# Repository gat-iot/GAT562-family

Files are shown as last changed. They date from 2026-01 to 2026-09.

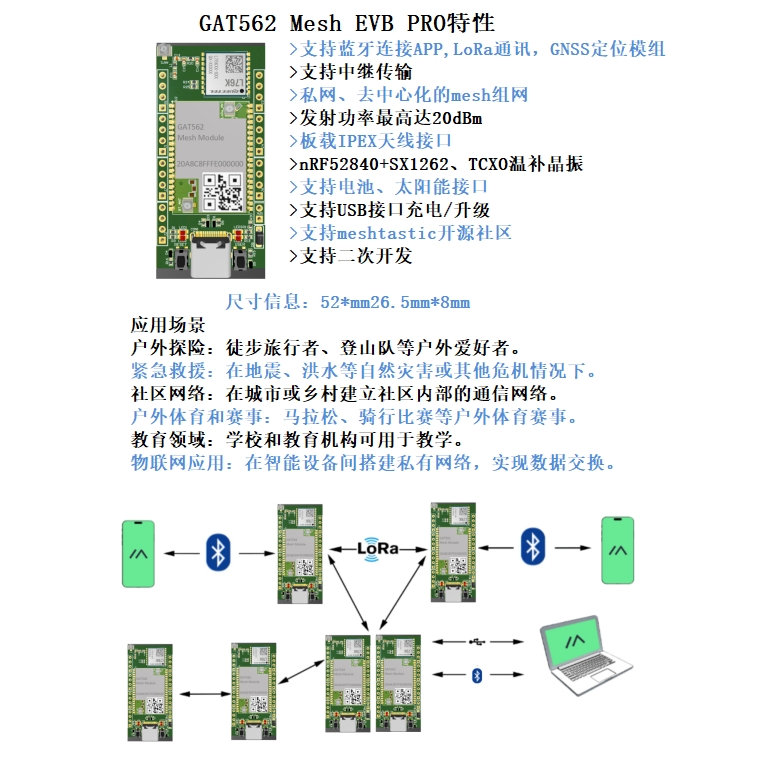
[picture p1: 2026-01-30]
GAT562 Mesh EVB PRO特性图.png

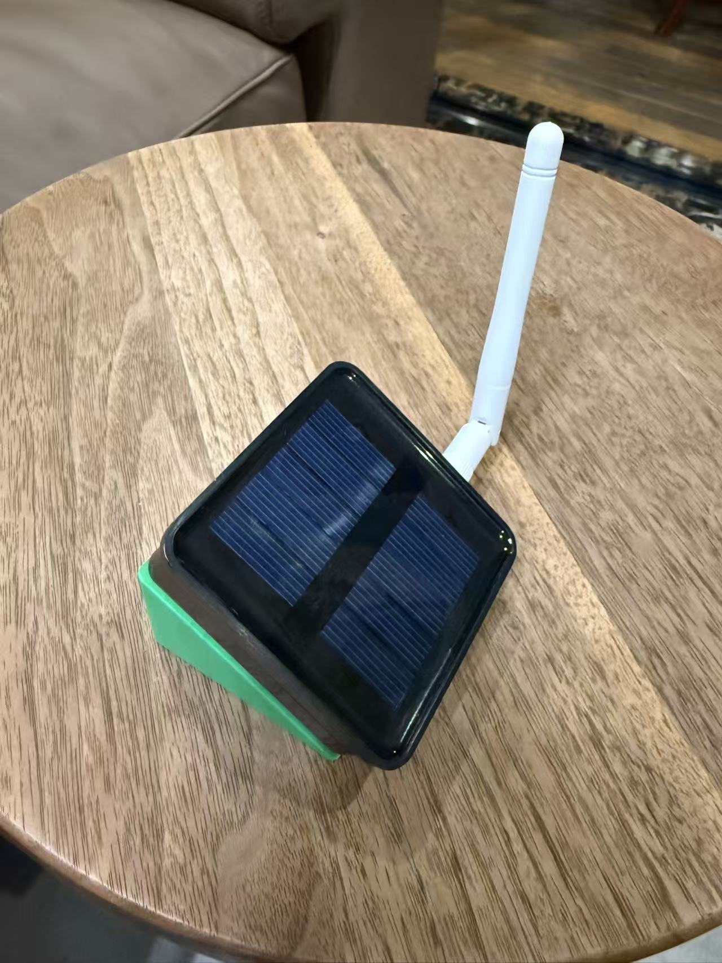
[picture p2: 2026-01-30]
GAT562 Mesh Solar Relay支架安装图.jpg

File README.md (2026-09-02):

GAT562 family介绍

GAT562 family是基于GAT562 Mesh Module 设计的产品系列，GAT562 Module基于nRF52840和SX1262设计的一体化模块，内置nRF52840主芯片，SX1262射频芯片搭配TCXO温补有源晶振，性能稳定，接口丰富，支持LoRa和蓝牙5.0。

GAT562 family目前支持的系统有meshtastic、meshcore、LoRa APRS

meshtastic固件对应仓库链接：https://github.com/gat-iot/firmware

meshcore固件对应官网链接：https://meshcore.co.uk/configurator/

LoRa APRS固件对应仓库链接：https://richonguzman.github.io/nrf52840-web-config/index.html

GAT562 Module接口丰富，拓展性强，模组自带meshtastic固件，支持外接拓展1.3英寸TFT显示屏和GPS模块、LED、蜂鸣器、按键、摇杆等外设功能。

GAT562 Module功耗低，主芯片采用nRF52840的性能与功耗天生优势，无需额外设计，性能稳定，简单可靠。

GAT562 family包含以下产品，种类齐全，形态丰富，可快速完整搭建属于自己的meshtastic网络。

开发板 GAT562 Mesh EVB Pro，适合产品快速验证与使用； GAT562 30S Board,适合产品快速验证与使用；

手持终端 GAT562 Mesh Tracker Pro，适合随身使用； GAT562 30S Mesh Kit， 发射功率30dbm，性能更强，适合贴身使用；

手表终端 GAT562 Mesh watch,适合随身使用；

中继： GAT562 Mesh solar relay（低成本优势）,适合楼顶或者户外中继，与终端终端互联互通，接力更远传输距离； GAT562 Mesh Solar rakay Pro（高性能优势），适合楼顶或者户外中继，与终端终端互联互通，接力更远传输距离； GAT562 Mesh Solar ralay Pro（高性能,高功率优势），适合楼顶或者户外中继，与终端终端互联互通，接力更远传输距离；

GAT562 Mesh family与Meshtastic/meshcore完全兼容，可以在Meshtastic/meshcore网络中更新体验最新的功能。Meshtastic/meshcore是一个社区驱动的开源项目，它允许在没有任何现有或可靠通信基础设施的地区合理的使用LoRa无线电进行远程离网通信。

GAT562 Mesh family与RAK4631模组IO完全兼容，可以烧录RAK4631固件；

优势 去中心化：不依赖中央服务器或基站，每个设备都可作为中继节点转发信息，网络中没有单点故障，即使部分节点出现问题，也不影响整体通信，网络的可靠性和稳定性更高。

长距离通信：利用 LoRa 等无线通信技术，可实现数公里甚至更远距离的通信，在无网络覆盖的偏远地区或广阔的户外空间优势明显。

离线通信：无需依赖互联网或移动网络，在没有手机信号或 Wi-Fi 的地方也能正常通信，满足特殊场景下的通信需求。

低功耗：采用低功耗的蓝牙低功耗（BLE）技术等，对硬件设备的电池消耗较小，可长时间使用，适合携带式设备，减少了充电的频率和难度。

开源可定制：软件开源，开发者能根据自身需求自由修改和扩展代码，进行二次开发，添加新功能或优化现有功能，满足不同用户的个性化需求。

跨平台兼容：支持多种硬件设备和操作系统，用户可选择适合自己的设备接入网络，如手机、平板电脑等，方便不同设备的用户之间进行通信。

成本较低：使用的硬件通常是价格较为低廉的开源硬件模块，相比专业的通信设备，成本大幅降低，易于推广和使用。

用户界面友好：设计了直观、简洁的用户界面，即使是非技术人员也能快速上手，方便用户进行设备配置、信息发送、位置共享等操作。

GAT562 30S Mesh Kit 3D外壳设计文件可自行前往下载：[https://makerworld.com.cn/zh/models/1718656-gat562-30kit-ji-chu-kuan-wai-ke](https://makerworld.com.cn/zh/models/1753346-gat562-22s-30swai-ke#profileId-1932721)

申明 外壳文件为3D打印文件，未经许可禁止商用，如涉及侵权自行承担后果，我方概不负责。

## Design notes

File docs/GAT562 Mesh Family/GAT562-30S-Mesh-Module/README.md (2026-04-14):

# GAT562 30S Mesh Module

## 产品简介

GAT562 30S Mesh Module 是 GAT562 系列的高功率增强版本，LoRa 发射功率提升至 **30 dBm（1 W）**，相比标准版的 22 dBm，通信距离大幅提升，是超远距离通信和太阳能中继的首选。

> **核心硬件**：nRF52840 + SX1262 + TCXO + 外置 PA，**与 RAK4631 模组 IO 完全兼容，可直接烧录 RAK4631 全系列固件**。

## 快速导航

| 文档 | 说明 |
|---|---|
| [概述](./Overview/) | 产品介绍、核心参数、产品系列 |
| [数据手册](./Datasheet/) | 完整技术规格、电气参数、封装信息 |
| [快速入门](./Quickstart/) | 环境搭建、固件烧录、开发指南 |

## 核心参数对比

| 参数 | GAT562 30S | GAT562 标准版 |
|---|---|---|
| LoRa 发射功率 | **30 dBm (1 W)** | 22 dBm (158 mW) |
| 通信距离 | 15 km+ | 8-15 km |
| 峰值电流 | ~900 mA | ~200 mA |
| 供电电压 | 3.3-5 V | 2.0-3.6 V |
| 推荐应用 | 远距离/中继站 | 手持/传感节点 |

## 相关链接

- GitHub: [gat-iot/GAT562-family](https://github.com/gat-iot/GAT562-family)
- Meshtastic: [meshtastic.org](https://meshtastic.org)
- 自定义固件: [gat-iot/meshtastic_fw](https://github.com/gat-iot/meshtastic_fw)

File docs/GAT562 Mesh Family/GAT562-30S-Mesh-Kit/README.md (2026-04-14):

# GAT562 30S Mesh Kit

## 产品简介

GAT562 30S Mesh Kit 是 GAT562 家族的旗舰手持终端套装，基于 GAT562 30S Mesh Module，配备 **30 dBm（1 W）高功率 LoRa**，是户外贴身使用的最强信号选择，适合野外探险、搜救、海上通信等需要超远距离离网通信的场景。

## 核心配置

| 组件 | 型号/规格 |
|---|---|
| **LoRa 模组** | GAT562 30S Mesh Module（**30 dBm 高功率**） |
| **主芯片** | nRF52840 + SX1262 + TCXO |
| **显示屏** | 1.3" TFT |
| **定位** | GPS 模块（内置/外接） |
| **输入** | 按键 + 摇杆 |
| **指示** | LED + 蜂鸣器 |
| **供电** | 内置锂电池（≥ 1000 mAh 推荐） |
| **发射功率** | **30 dBm（1 W）** |
| **通信距离** | 15 km+（开阔地，视天线而定） |

## 与 GAT562 Mesh Tracker Pro 的区别

| 对比项 | GAT562 30S Mesh Kit | GAT562 Mesh Tracker Pro |
|---|---|---|
| 发射功率 | **30 dBm (1 W)** | 22 dBm (158 mW) |
| 通信距离 | **15 km+** | 8-15 km |
| 适用场景 | 超远距离/野外 | 中远距离/城郊 |
| 供电要求 | 高（峰值 900 mA） | 中（峰值 200 mA） |

## 3D 外壳

GAT562 30S Mesh Kit 提供 3D 打印外壳（STL 文件），可在 MakerWorld 下载：

> 📦 [https://makerworld.com.cn/zh/models/1718656-gat562-30kit-ji-chu-kuan-wai-ke](https://makerworld.com.cn/zh/models/1718656-gat562-30kit-ji-chu-kuan-wai-ke)

> ⚠️ 外壳文件为 3D 打印用途，未经许可**禁止商用**，如涉及侵权自行承担后果。

## 固件支持

| 固件 | 来源 | 说明 |
|---|---|---|
| Meshtastic 官方 | 内置 | 英文界面 |
| 中文定制固件 | [pepefrog1234](https://github.com/gat-iot/meshtastic_fw) | 中文界面，支持 30 秒高频位置发送 |

## 相关文档

- [GAT562 30S Mesh Module 数据手册 →](../GAT562-30S-Mesh-Module/Datasheet/)
- [快速入门 →](../GAT562-30S-Mesh-Module/Quickstart/)
- [GitHub 资源](https://github.com/gat-iot/GAT562-family)

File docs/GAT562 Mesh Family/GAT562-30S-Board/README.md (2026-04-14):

# GAT562 30S Board

## 产品简介

GAT562 30S Board 是一款基于 **GAT562 30S Mesh Module** 的开发评估板，搭载 30 dBm 高功率 LoRa 模组，适合需要超远距离通信的产品快速验证与评估。

## 硬件特性

| 特性 | 说明 |
|---|---|
| **核心模组** | GAT562 30S Mesh Module（30 dBm 高功率） |
| **供电** | USB Type-C / DC Jack / 电池接口（≥5V/1A） |
| **天线接口** | IPEX / SMA 可选 |
| **显示接口** | 预留 1.3" TFT 屏幕接口 |
| **调试接口** | USB 烧录 / SWD |
| **尺寸** | 约 85 × 60 mm |

> ⚠️ **供电注意**：30S Board 在高功率发射时峰值电流 ~900 mA，必须使用 5V/1A 以上电源。

## 相关文档

- [GAT562 30S Mesh Module 数据手册 →](../GAT562-30S-Mesh-Module/Datasheet/)
- [快速入门 →](../GAT562-30S-Mesh-Module/Quickstart/)
- [GitHub 资源](https://github.com/gat-iot/GAT562-family)

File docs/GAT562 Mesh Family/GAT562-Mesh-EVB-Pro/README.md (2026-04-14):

# GAT562 Mesh EVB Pro

## 产品简介

GAT562 Mesh EVB Pro 是一款基于 **GAT562 Mesh Module** 的多功能开发评估板，板载 GAT562 模组核心，引出全部 IO 引脚，预装 Meshtastic 固件，适合快速功能验证、产品评估和二次开发。

## 硬件特性

| 特性 | 说明 |
|---|---|
| **核心模组** | GAT562 Mesh Module（nRF52840 + SX1262 + TCXO） |
| **发射功率** | 最高 22 dBm（LoRa PA Boost） |
| **供电方式** | USB Type-C / DC Jack / 电池接口 |
| **调试接口** | 原生 USB（烧录 + 调试）/ SWD 接口 |
| **显示接口** | 预留 1.3" TFT 屏幕接口 |
| **GPS 接口** | 预留 GPS 模块接口（UART） |
| **IO 扩展** | 全部引脚通过排针引出（兼容 RAK5005-O） |
| **板载外设** | LED × 2 / 按键 × 2 / 复位键 |
| **尺寸** | 约 85 × 60 mm |

## IO 引脚图

> 完整 IO 引脚定义图：[GAT562 Mesh EVB PRO IO.png](https://github.com/gat-iot/GAT562-family/blob/main/GAT562%20Mesh%20EVB%20PRO%20IO.png)

## 快速入门

### 步骤 1：连接设备

1. 用 USB-C 数据线连接 EVB Pro 到电脑
2. 蓝色 LED 亮起表示开机正常
3. 在电脑上识别到 USB 串口（COMx）

### 步骤 2：配置 Meshtastic

1. 手机安装 Meshtastic App
2. 打开 App，搜索 BLE 设备
3. 连接后配置频道、节点名称

### 步骤 3：烧录固件

- **Web Flasher**：[meshtastic.org/flasher](https://meshtastic.org/flasher)，选择 RAK4631
- **Arduino IDE**：选择 `WisBlock Core → RAK4631` 开发板

## 扩展接口

| 接口 | 说明 |
|---|---|
| **Slot A / B / C / D** | WisBlock 兼容传感器扩展槽 |
| **IO 排针** | 全部 GPIO 引出 |
| **USB** | 烧录 / 供电 / 串口调试 |
| **SWD** | JTAG / SWD 调试 |
| **GPS 接口** | 串口连接 GPS 模块 |
| **TFT 屏幕** | SPI 接口 1.3" 屏幕 |

## 相关文档

- [GAT562 Mesh Module 数据手册 →](../GAT562-Mesh-Module/Datasheet/)
- [快速入门 →](../GAT562-Mesh-Module/Quickstart/)
- [GitHub 资源](https://github.com/gat-iot/GAT562-family)

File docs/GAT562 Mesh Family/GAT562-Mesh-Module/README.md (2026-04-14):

---
rak_desc
 GAT562 Mesh Module 是一款基于 Nordic nRF52840 + Semtech SX1262 的 LoRa + BLE 融合模组，完全兼容 RAK4631 模组 IO 接口，支持 Meshtastic 开源固件，广泛应用于离网通信、Mesh 网络、定位追踪等物联网场景。
 rak_img
 /assets/images/wisblock/gat562/GAT562-Module.png

 prev
 ../
 next
 ./Overview/

 tags

 gat562
 gat562-30s
 wisblock
 meshtastic
 lora
 bluetooth
 nrf52840
 sx1262
 mesh
 high-power

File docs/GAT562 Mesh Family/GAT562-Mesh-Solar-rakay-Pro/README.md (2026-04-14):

# GAT562 Mesh Solar rakay Pro（高性能太阳能中继）

## 产品简介

GAT562 Mesh Solar rakay Pro 是 GAT562 家族的高性能太阳能中继方案，相比低成本版 Solar Relay，搭载 **22 dBm 高性能模组 + 更大容量的太阳能系统**，适合需要更稳定、更强信号覆盖的长期部署场景。

## 核心配置

| 组件 | 规格 |
|---|---|
| **LoRa 模组** | GAT562 Mesh Module（22 dBm）|
| **中继类型** | 高性能 |
| **太阳能板** | 更大面积（视部署环境）|
| **锂电池** | 更大容量 |
| **天线** | 高增益外置天线 |
| **防护等级** | IP65+ 户外防护外壳（推荐）|

## 与 Solar Relay（低成本版）的区别

| 对比项 | Solar Relay（低成本） | Solar rakay Pro（高性能）|
|---|---|---|
| 太阳能板 | 标准尺寸 | 更大面积 |
| 锂电池 | 基础容量 | 大容量（更长续航）|
| 目标场景 | 短期/临时部署 | 长期稳定运营 |
| 覆盖能力 | 中等 | 强 |

## 相关文档

- [GAT562 Mesh Module 数据手册 →](../GAT562-Mesh-Module/Datasheet/)
- [Meshtastic 官方](https://meshtastic.org)
- [GitHub 资源](https://github.com/gat-iot/GAT562-family)

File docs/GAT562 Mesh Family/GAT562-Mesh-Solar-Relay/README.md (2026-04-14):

# GAT562 Mesh Solar Relay（低成本太阳能中继）

## 产品简介

GAT562 Mesh Solar Relay 是一款基于 GAT562 Mesh Module 的低成本楼顶/户外固定中继设备，预装 Meshtastic 固件，搭配太阳能电池板和锂电池，形成完全自主供电的 Mesh 网络节点，显著延伸 Mesh 通信覆盖范围。

## 核心配置

| 组件 | 规格 |
|---|---|
| **LoRa 模组** | GAT562 Mesh Module（22 dBm） |
| **发射功率** | 22 dBm |
| **中继类型** | 低成本 |
| **供电方案** | 太阳能 + 锂电池 |
| **天线** | 外置高增益天线（推荐 5dBi+） |
| **安装方式** | 壁挂 / 抱杆 |

## 典型部署

```
     楼顶安装
        │
   ┌────▼────┐
   │  LoRa    │◄─────── 接收来自手持终端的消息
   │  天线    │
   └────┬────┘
        │ LoRa Mesh（接力转发）
   ┌────▼────┐
   │ 30S 中继 │◄─────── 继续转发到更远的节点
   └─────────┘
        │
   ┌────▼────┐
   │ 太阳能板 │
   └────┬────┘
        │
   ┌────▼────┐
   │  锂电池  │  24/7 自立供电
   └─────────┘
```

## 配置建议

| 参数 | 推荐值 |
|---|---|
| LoRa 发射功率 | 20~22 dBm（白天）|
| 睡眠间隔 | 按需设置（Mesh 路由自动唤醒）|
| 天线类型 | 全向 5dBi（覆盖均匀）或定向（点对点）|
| 天线安装高度 | 越高越好（视距传播）|
| 锂电池容量 | ≥ 5000 mAh（应对连续阴天）|

## 优势

- ✅ **低成本**：适合大面积铺设
- ✅ **自供电**：太阳能 + 锂电池，零电费
- ✅ **免维护**：Mesh 自组网，自动路由
- ✅ **延伸距离**：显著扩大 Mesh 网络覆盖半径

## 相关文档

- [GAT562 Mesh Module 数据手册 →](../GAT562-Mesh-Module/Datasheet/)
- [Meshtastic 中继配置指南](https://meshtastic.org/docs/)
- [GitHub 资源](https://github.com/gat-iot/GAT562-family)

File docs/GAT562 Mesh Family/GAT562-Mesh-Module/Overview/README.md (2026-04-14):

# GAT562 Mesh Module 概述

## 产品简介

GAT562 Mesh Module 是基于 Nordic nRF52840 + Semtech SX1262 一体化设计的 LoRa + BLE 融合模组，**与 RAK4631 模组 IO 完全兼容，可直接烧录 RAK4631 固件**。模组搭配 TCXO 温补有源晶振，性能稳定，接口丰富，预装 Meshtastic 开源固件，开箱即用。

## 核心特性

| 特性 | 说明 |
|---|---|
| **主芯片** | Nordic nRF52840 (ARM Cortex-M4, 64MHz, 1MB Flash, 256KB RAM) |
| **射频芯片** | Semtech SX1262 LoRa |
| **通信方式** | LoRa + BLE 5.0 |
| **温补晶振** | TCXO（提升频率稳定性与通信距离） |
| **发射功率** | 标准模组：最高 22 dBm（LoRa PA Boost） |
| **接收灵敏度** | -148 dBm（LoRa @ SF12, BW 125kHz） |
| **睡眠功耗** | 低至 2 µA（深度睡眠模式） |
| **供电电压** | 2.0 ~ 3.6 V |
| **工作温度** | -40°C ~ +85°C |
| **模块尺寸** | 约 20 × 30 mm |
| **接口** | UART / I2C / GPIO / USB / SWD |
| **固件** | 预装 Meshtastic，支持外接 1.3" TFT 显示屏、GPS、LED、蜂鸣器、按键、摇杆 |
| **兼容性** | 与 RAK4631 模组 IO 100% 兼容，可烧录 RAK4631-Arduino / RUI3 固件 |

## 支持频段

| 型号后缀 | 适用地区 | 频率范围 |
|---|---|---|
| GAT562(L) | 中国 | CN470 |
| GAT562(L) | 欧洲 | EU433 |
| GAT562(H) | 欧洲 | EU868 |
| GAT562(H) | 北美 | US915 |
| GAT562(H) | 澳大利亚 | AU915 |
| GAT562(H) | 韩国 | KR920 |
| GAT562(H) | 亚洲 | AS923-1/2/3/4 |
| GAT562(H) | 印度 | IN865 |
| GAT562(H) | 俄罗斯 | RU864 |

> **提示**：购买时请确认型号（H = 高频段 / L = 低频段）符合您所在地区的无线电法规。

## 产品系列

GAT562 模组系列包括：

| 产品 | 描述 | 适用场景 |
|---|---|---|
| **GAT562 Mesh Module** | 基础模组，22 dBm 发射功率 | 产品二次开发设计 |
| **GAT562 30S Mesh Module** | 增强模组，30 dBm 发射功率 | 远距离产品二次开发 |
| **GAT562 Mesh EVB Pro** | 开发板 | 快速验证与评估 |
| **GAT562 30S Board** | 30S 开发板 | 快速验证 30S 模组 |
| **GAT562 Mesh Tracker Pro** | 手持终端 | 便携使用 |
| **GAT562 30S Mesh Kit** | 30S 手持终端套装 | 强信号贴身设备 |
| **GAT562 Mesh Watch** | 手表形态终端 | 可穿戴场景 |
| **GAT562 Mesh Solar Relay** | 低成本太阳能中继 | 楼顶/户外固定中继 |
| **GAT562 Mesh Solar rakay Pro** | 高性能太阳能中继 | 强性能固定中继 |
| **GAT562 30S Mesh Solar rakay Pro** | 高功率太阳能中继 | 远距离固定中继 |

## 系统架构

```
┌─────────────────────────────────────┐
│         GAT562 Mesh Module          │
│  ┌───────────────┐  ┌────────────┐ │
│  │  nRF52840     │  │  SX1262    │ │
│  │  (MCU)        │◄─┤  (LoRa RF) │ │
│  │               │  │            │ │
│  │  64MHz ARM    │  │  TCXO      │ │
│  │  1MB Flash    │  │  22dBm     │ │
│  └───────┬───────┘  └──────┬─────┘ │
│          │                 │       │
│          │    BLE 5.0      │       │
│          │    LoRa         │       │
│          └───────┬─────────┘       │
│                  │                 │
│            I/O Port                │
│     (UART / I2C / GPIO / USB)      │
└─────────────────────────────────────┘
```

## 扩展外设支持

GAT562 Mesh Module 模组支持丰富的外部设备扩展：

- **显示屏**：1.3 英寸 TFT 屏幕（SPI 接口）
- **定位模块**：GPS 模块（串口连接）
- **输入设备**：按键、摇杆
- **指示输出**：LED 指示灯、蜂鸣器
- **无线连接**：蓝牙 5.0（近场配置与数据传输）
- **LoRa Mesh**：点对点、Mesh 网络自组网

## Mesh 网络优势

- **去中心化**：无单点故障，每个节点均可转发
- **长距离**：LoRa 穿透性强，支持数公里通信
- **离线通信**：无需互联网，手机无信号也能工作
- **低功耗**：nRF52 架构天然低功耗，待机持久
- **开源可定制**：Meshtastic 固件完全开源，支持二次开发
- **跨平台**：Android / iOS / Web 多端管理

## 与 RAK4631 的关系

GAT562 Mesh Module 基于与 RAK4631 相同的核心硬件平台（nRF52840 + SX1262），两者的主要区别：

| 对比项 | RAK4631 | GAT562 Mesh Module |
|---|---|---|
| **核心硬件** | nRF52840 + SX1262 | nRF52840 + SX1262 |
| **IO 接口** | WisBlock 连接器 | WisBlock 连接器（兼容） |
| **官方固件** | RAK4631-Arduino / RUI3 | Meshtastic（预装） |
| **显示屏** | 需外接 | 内置 1.3" TFT 支持 |
| **GPS** | 需外接 | 支持内置/外接 |
| **封装** | WisBlock Core 模块 | 模组形态 |
| **RAK4631 固件** | 原生支持 | **完全兼容，可直接烧录** |

## 资源链接

- **Meshtastic 官方**：[https://meshtastic.org](https://meshtastic.org)
- **Meshtastic 固件**：[https://github.com/gat-iot/meshtastic_fw](https://github.com/gat-iot/meshtastic_fw)
- **GAT562 GitHub**：[https://github.com/gat-iot/GAT562-family](https://github.com/gat-iot/GAT562-family)
- **RAK4631 文档**：[RAK4631 WisBlock Core](/RAKWireless/rakwireless-docs/blob/master/docs/Product-Categories/WisBlock/RAK4631/README.md)

## 下一步

- [快速入门 →](./Quickstart/)  — 环境搭建与固件烧录
- [数据手册 →](./Datasheet/)  — 完整技术规格

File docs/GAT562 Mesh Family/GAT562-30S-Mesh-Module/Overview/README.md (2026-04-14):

# GAT562 30S Mesh Module 概述

## 产品简介

GAT562 30S Mesh Module 是 GAT562 家族中的**高性能增强版本**，相较于标准 GAT562 Mesh Module，其核心升级在于内置外置功率放大器（PA），LoRa 发射功率从标准版的 22 dBm 提升至 **30 dBm（1 W）**，大幅扩展通信覆盖范围，尤其适合山区、海上、荒野等超远距离通信场景。

其他核心配置与 GAT562 Mesh Module 保持一致，同样基于 nRF52840 + SX1262 + TCXO，**与 RAK4631 模组 IO 完全兼容，可直接烧录 RAK4631 全系列固件**。

## 核心特性

| 特性 | GAT562 30S | GAT562 标准版 | 说明 |
|---|---|---|---|
| **LoRa 发射功率** | **30 dBm (1 W)** | 22 dBm (158 mW) | 外置 PA，显著提升通信距离 |
| **主芯片** | nRF52840 | nRF52840 | ARM Cortex-M4, 64MHz |
| **射频芯片** | SX1262 + TCXO | SX1262 + TCXO | 性能一致 |
| **BLE 发射功率** | +4 dBm | +4 dBm | — |
| **通信距离** | 15 km+（开阔地） | 8-15 km（开阔地） | 视天线和环境而定 |
| **睡眠功耗** | ~2 µA | ~2 µA | 仅 MCU 休眠 |
| **供电电压** | 3.3 ~ 5 V（增强PA供电） | 2.0 ~ 3.6 V | 30S 需更高供电电流 |
| **RAK4631 兼容** | ✅ 完全兼容 | ✅ 完全兼容 | 固件可直接互换 |

## 典型功耗对比

| 模式 | GAT562 30S | GAT562 标准版 |
|---|---|---|
| 深度睡眠 | ~2 µA | ~2 µA |
| 接收 (LoRa) | ~18 mA | ~17 mA |
| 发射 @17 dBm | ~180 mA | ~92 mA |
| **发射 @30 dBm** | **~900 mA** | N/A |
| **发射 @22 dBm** | **~200 mA** | ~125 mA |

> ⚠️ **注意**：30 dBm 高功率发射时峰值电流可达 ~900 mA，请确保供电能力充足（推荐 5V/1A 以上），并注意散热。

## 适用场景

| 场景 | 推荐版本 | 说明 |
|---|---|---|
| 城市近距离 Mesh | GAT562 标准版 | 低功耗够用 |
| 郊区 / 城郊通信 | 两者皆可 | 标准版 22 dBm 可覆盖 |
| **山区 / 海上通信** | **GAT562 30S** | 30 dBm 穿透力强 |
| **野外探险 / 搜救** | **GAT562 30S** | 超远距离通信 |
| 太阳能中继站 | GAT562 30S | 高功率中继首选 |
| 低功耗传感节点 | GAT562 标准版 | 电池供电友好 |

## 支持频段（与 GAT562 一致）

| 型号后缀 | 地区 | 频率 |
|---|---|---|
| 30S(L) | 中国 / 欧洲低频 | CN470 / EU433 |
| 30S(H) | 全球高频地区 | EU868 / US915 / AU915 / KR920 / AS923 / IN865 / RU864 |

## 产品定位

```
GAT562 产品系列定位

  远距离 ←————————————————————————————→ 近距离
     │                                              │
     │  ┌──────────────────────────────┐             │
     │  │  GAT562 30S Series            │             │
     │  │  30 dBm · 太阳能中继首选       │             │
     │  └──────────────────────────────┘             │
     │  ┌──────────────────────────────┐             │
     │  │  GAT562 Standard Series      │             │
  ┌──┴──┴──────────────────────────────┴────────┐   │
  │  22 dBm · 手持终端 / 开发板 / 模组             │   │
  └──────────────────────────────────────────────┘   │
```

## 3D 外壳设计

GAT562 30S Mesh Kit 的 3D 外壳设计文件（STL）可在 MakerWorld 下载：

> [https://makerworld.com.cn/zh/models/1718656-gat562-30kit-ji-chu-kuan-wai-ke](https://makerworld.com.cn/zh/models/1718656-gat562-30kit-ji-chu-kuan-wai-ke)

外壳为 3D 打印设计文件，未经许可**禁止商用**，如涉及侵权由使用者自行承担。

## 资源链接

- **硬件设计文件**：[gat-iot/GAT562-family](https://github.com/gat-iot/GAT562-family)
- **Meshtastic 固件**：[meshtastic.org](https://meshtastic.org)
- **自定义固件**（开源中文版）：[gat-iot/meshtastic_fw](https://github.com/gat-iot/meshtastic_fw)

## 下一步

- [快速入门 →](./Quickstart/)
- [数据手册 →](./Datasheet/)

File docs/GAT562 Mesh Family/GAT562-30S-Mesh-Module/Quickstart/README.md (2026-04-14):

# GAT562 30S Mesh Module 快速入门

## 与 GAT562 标准版的差异

GAT562 30S 的快速入门流程与 GAT562 标准版基本一致，主要差异在于：

| 差异项 | 说明 |
|---|---|
| **供电要求更高** | 30 dBm 发射时峰值电流 ~900 mA，必须使用 ≥5V/1A 电源 |
| **天线接口** | 30S 采用 IPEX/u.FL 射频座（非邮票孔），需使用 IPEX 天线线或转接线 |
| **发热注意** | 长时间 30 dBm 发射时模组会发热，建议加强散热 |

## 供电注意事项

> ⚠️ **关键警告**：GAT562 30S 在 30 dBm 发射时峰值电流约 **900 mA**。如果使用 USB 供电，请确保使用 **USB 3.0 端口**或 **5V/1A 以上**的电源适配器。如果使用锂电池供电，请使用 **3.7V 锂聚合物电池（容量 ≥ 1000 mAh）**。

**推荐供电方案：**
```
✅ 推荐：
  - USB 5V/1A 以上电源适配器 + USB-C 数据线
  - 3.7V LiPo 电池（≥1000mAh）+ USB 充电管理模块
  - 太阳能电池板 + LiPo 电池（太阳能中继场景）

❌ 不推荐：
  - USB 2.0 电脑端口（仅提供 500mA）
  - 直接使用 3.3V/500mA 电源（供电不足，发射会断电重启）
```

## 天线选择

| 天线类型 | 适用场景 | 建议 |
|---|---|---|
| IPEX 1/4 波段天线 | 便携设备 | 小型化，轻便 |
| SMA 直立天线（3dBi） | 固定中继 | 增益更高 |
| SMA 胶棒天线（5dBi） | 远距离固定点 | 高增益首选 |
| 外置高增益天线 | 楼顶中继站 | 10dBi+ 全向/定向天线 |

> **天线匹配**：确保天线阻抗为 **50 Ω**，并使用阻抗匹配的射频线缆（如同轴线）。

## Meshtastic 固件烧录

### 方法一：Web Flasher（推荐）

1. 访问 [meshtastic.org/flasher](https://meshtastic.org/flasher)
2. 选择目标设备：`RAK4631`（GAT562 30S IO 兼容）
3. 选择版本和频段（与您的 30S 模组匹配）
4. 用 USB 连接设备
5. 点击 **Flash**

### 方法二：蓝牙 OTA

1. 开机后，打开 Meshtastic App
2. 连接设备（BLE）
3. 设置 → 检查固件更新 → 安装

### 方法三：自定义开源固件

pepefrog1234 提供了 GAT562 30S 专用 Meshtastic 固件（开源中文界面，位置发送间隔可缩短至 30 秒）：

> **仓库**：[https://github.com/gat-iot/meshtastic_fw](https://github.com/gat-iot/meshtastic_fw)

特点：
- ✅ 支持中文界面
- ✅ 位置发送间隔最短 **30 秒**（适合高频追踪场景）
- ⚠️ 电池电量显示可能不准确
- ⚠️ 建议充分测试后再用于生产环境

## 固件更新邮件

如需获取最新固件，请发邮件至：

> 📧 **farce.chen@foxmail.com**

## LoRa 参数配置建议（30S 专用）

由于 30 dBm 高功率特性，建议以下配置：

| 场景 | 发射功率 | 扩频因子 | 带宽 | 说明 |
|---|---|---|---|---|
| 超远距离固定中继 | 30 dBm | SF10 | 125 kHz | 最大覆盖 |
| 户外探险（平衡模式） | 22 dBm | SF9 | 250 kHz | 距离与功耗平衡 |
| 低功耗传感器节点 | 10 dBm | SF7 | 500 kHz | 省电优先 |

## 太阳能中继应用

GAT562 30S 是太阳能中继站的理想选择：

```
┌──────────────────────────────────────────────┐
│                                              │
│  ┌─────────┐    LoRa Mesh     ┌─────────┐  │
│  │ 手持终端 │◄──────────────►│ 30S 中继 │  │
│  └─────────┘    (30 dBm)      └────┬────┘  │
│                                     │        │
│                              ┌──────▼────┐  │
│                              │  太阳能板  │  │
│                              └──────┬────┘  │
│                                     │        │
│                              ┌──────▼────┐  │
│                              │ LiPo 电池 │  │
│                              │  (供电)   │  │
│                              └───────────┘  │
└──────────────────────────────────────────────┘
```

---

## 相关文档

- [GAT562 30S Mesh Module 概述 →](./)
- [数据手册 →](../Datasheet/)
- [Meshtastic 官方文档](https://meshtastic.org/docs/)
- [MakerWorld 3D 外壳](https://makerworld.com.cn/zh/models/1718656-gat562-30kit-ji-chu-kuan-wai-ke)

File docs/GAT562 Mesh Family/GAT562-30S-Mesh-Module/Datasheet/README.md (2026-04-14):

# GAT562 30S Mesh Module 数据手册

## 硬件规格（与 GAT562 标准版对比）

### 核心差异：功率放大器（PA）

| 参数 | GAT562 30S | GAT562 标准版 |
|---|---|---|
| **LoRa 发射功率** | **30 dBm (1 W)** | 22 dBm |
| PA 架构 | 外置 PA + SX1262 | SX1262 内置 PA（PA_BOOST） |
| 典型 Tx 电流 @30 dBm | ~900 mA | N/A |
| 典型 Tx 电流 @22 dBm | ~200 mA | ~125 mA |
| 典型 Tx 电流 @17 dBm | ~180 mA | ~92 mA |
| 供电电压范围 | 3.3 V ~ 5 V | 2.0 V ~ 3.6 V |
| 推荐供电电流 | ≥ 1 A | ≥ 300 mA |

### 芯片组合（与标准版一致）

| 器件 | 型号 | 厂商 |
|---|---|---|
| MCU | nRF52840 | Nordic Semiconductor |
| LoRa RF | SX1262 | Semtech |
| 功率放大器 | 外置 PA | — |
| 温补晶振 | TCXO | — |

### 尺寸与封装

| 参数 | 值 |
|---|-----|
| 模块尺寸 | 约 20 × 30 mm（与标准版相同） |
| 安装孔距 | 兼容 RAK5005-O 底板 |
| 连接器 | WisBlock 标准连接器（兼容 RAK4631） |
| **天线接口** | **IPEX / u.FL 射频座（PA 输出端）** |

### 完整电气规格

| 符号 | 描述 | 最小 | 典型 | 最大 | 单位 |
|---|---|---|---|---|---|
| VDD_3V3 | 3.3V 电源 | 3.0 | 3.3 | 3.6 | V |
| VDD_PA | PA 电源（30S 专用） | 3.3 | 5.0 | 5.5 | V |
| I_TX_30dBm | 30 dBm 发射电流 | — | 900 | — | mA |
| I_TX_22dBm | 22 dBm 发射电流 | — | 200 | — | mA |
| I_RX | 接收电流 | — | 18 | — | mA |
| I_Sleep | 深度睡眠电流 | — | 2 | — | µA |
| Temp | 工作温度 | -40 | — | +85 | °C |

### LoRa 射频规格

| 参数 | 值 |
|---|-----|
| 频率范围 | 150 ~ 960 MHz（依型号 H/L） |
| 带宽 | 7.8 kHz ~ 500 kHz |
| **最大发射功率** | **+30 dBm**（外置 PA） |
| 接收灵敏度 | -148 dBm（SF12, BW 125kHz） |
| 扩频因子 | SF5 ~ SF12 |

### 认证说明

GAT562 30S 由于发射功率较高（30 dBm / 1W），在某些地区使用可能需要额外认证或使用许可：

> ⚠️ **法规提示**：
> - **EU（欧洲）**：30 dBm 在某些频段（如 868 MHz）有占空比限制，请参考 ETSI EN 300 220
> - **北美（US915）**：30 dBm 在部分频段可能超出免许可功率上限
> - **中国（CN470）**：请遵守当地 LoRa 频段法规
> - 使用前请确认当地无线电法规，确保合规使用

### 封装文件

| 文件 | 说明 |
|---|---|
| GAT562 30S Mesh Module 封装定义.pdf | 焊盘尺寸、SMT 封装图 |
| GAT562 30S Mesh KIT V1.1 SCH.pdf | 30S 开发板完整原理图 |
| GAT562 30S Mesh Kit介绍.pdf | 产品介绍与硬件说明 |

> 下载地址：[gat-iot/GAT562-family](https://github.com/gat-iot/GAT562-family)

---

## 相关文档

- [GAT562 30S Mesh Module 概述 →](./)
- [快速入门 →](../Quickstart/)

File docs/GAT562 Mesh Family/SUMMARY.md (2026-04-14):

# Summary - GAT562 Mesh Family

## 产品系列

* [GAT562 Mesh Family 总览](GAT562-Mesh-Family/README.md)

## 模组

* [GAT562 Mesh Module](GAT562-Mesh-Module/README.md)
  * [概述](GAT562-Mesh-Module/Overview/README.md)
  * [数据手册](GAT562-Mesh-Module/Datasheet/README.md)
  * [快速入门](GAT562-Mesh-Module/Quickstart/README.md)
* [GAT562 30S Mesh Module](GAT562-30S-Mesh-Module/README.md)
  * [概述](GAT562-30S-Mesh-Module/Overview/README.md)
  * [数据手册](GAT562-30S-Mesh-Module/Datasheet/README.md)
  * [快速入门](GAT562-30S-Mesh-Module/Quickstart/README.md)

## 开发板

* [GAT562 Mesh EVB Pro](GAT562-Mesh-EVB-Pro/README.md)
* [GAT562 30S Board](GAT562-30S-Board/README.md)

## 手持终端

* [GAT562 Mesh Tracker Pro](GAT562-Mesh-Tracker-Pro/README.md)
* [GAT562 30S Mesh Kit](GAT562-30S-Mesh-Kit/README.md)
* [GAT562 Mesh Watch](GAT562-Mesh-Watch/README.md)

## 中继设备

* [GAT562 Mesh Solar Relay（低成本）](GAT562-Mesh-Solar-Relay/README.md)
* [GAT562 Mesh Solar rakay Pro（高性能）](GAT562-Mesh-Solar-rakay-Pro/README.md)
* [GAT562 30S Mesh Solar rakay Pro（高功率）](GAT562-30S-Mesh-Solar-rakay-Pro/README.md)

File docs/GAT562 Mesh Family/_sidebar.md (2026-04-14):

## 📦 GAT562 产品系列

### 🔲 模组
- [GAT562 Mesh Module](./GAT562-Mesh-Module/)
  - [概述](./GAT562-Mesh-Module/Overview/)
  - [数据手册](./GAT562-Mesh-Module/Datasheet/)
  - [快速入门](./GAT562-Mesh-Module/Quickstart/)
- [GAT562 30S Mesh Module](./GAT562-30S-Mesh-Module/)
  - [概述](./GAT562-30S-Mesh-Module/Overview/)
  - [数据手册](./GAT562-30S-Mesh-Module/Datasheet/)
  - [快速入门](./GAT562-30S-Mesh-Module/Quickstart/)

### 🖥️ 开发板
- [GAT562 Mesh EVB Pro](./GAT562-Mesh-EVB-Pro/)
- [GAT562 30S Board](./GAT562-30S-Board/)

### 📱 手持终端
- [GAT562 Mesh Tracker Pro](./GAT562-Mesh-Tracker-Pro/)
- [GAT562 30S Mesh Kit](./GAT562-30S-Mesh-Kit/)
- [GAT562 Mesh Watch](./GAT562-Mesh-Watch/)

### 🛰️ 中继设备
- [GAT562 Mesh Solar Relay](./GAT562-Mesh-Solar-Relay/)（低成本）
- [GAT562 Mesh Solar rakay Pro](./GAT562-Mesh-Solar-rakay-Pro/)（高性能）
- [GAT562 30S Mesh Solar rakay Pro](./GAT562-30S-Mesh-Solar-rakay-Pro/)（高功率）

---

## 🔗 外部资源

- [Meshtastic 官网](https://meshtastic.org)
- [Meshtastic GitHub](https://github.com/gat-iot/meshtastic_fw)
- [GAT562 GitHub](https://github.com/gat-iot/GAT562-family)
- [RAK4631 官方文档](./RAK4631/)（硬件兼容参考）

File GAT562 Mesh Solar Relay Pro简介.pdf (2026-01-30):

# GAT562 Mesh Solar Relay Pro 简介

## GAT562 Mesh Solar Relay Pro 是基于 GAT562 Mesh EVB Pro 设计的 meshtastic 中继器，支持 LoRa

和蓝牙 5.0。集成太阳能充电(内置 5000mA 锂电池），具有中继通信能力与低功耗设计。

## GAT562 Mesh Solar Relay Pro 与 Meshtastic 完全兼容，可以在 Meshtastic 网络中更新体验最新的功

能。Meshtastic 是一个社区驱动的开源项目，它允许在没有任何现有或可靠通信基础设施的地区合理的使 用 LoRa 无线电进行远程离网通信。

优势
- 去中心化：不依赖中央服务器或基站，每个设备都可作为中继节点转发信息，网络中没有单点故障，

即使部分节点出现问题，也不影响整体通信，网络的可靠性和稳定性更高。
- 长距离通信：利用 LoRa 等无线通信技术，可实现数公里甚至更远距离的通信，在无网络覆盖的偏

远地区或广阔的户外空间优势明显。
- 离线通信：无需依赖互联网或移动网络，在没有手机信号或 Wi-Fi 的地方也能正常通信，满足特殊

场景下的通信需求。
- 低功耗：采用低功耗的蓝牙低功耗（BLE）技术等，对硬件设备的电池消耗较小，可长时间使用，适

合携带式设备，减少了充电的频率和难度。
- 开源可定制：软件开源，开发者能根据自身需求自由修改和扩展代码，进行二次开发，添加新功能或

优化现有功能，满足不同用户的个性化需求。
- 跨平台兼容：支持多种硬件设备和操作系统，用户可选择适合自己的设备接入网络，如手机、平板电

脑等，方便不同设备的用户之间进行通信。
- 成本较低：使用的硬件通常是价格较为低廉的开源硬件模块，相比专业的通信设备，成本大幅降低，

易于推广和使用。
- 用户界面友好：设计了直观、简洁的用户界面，即使是非技术人员也能快速上手，方便用户进行设备

配置、信息发送、位置共享等操作。

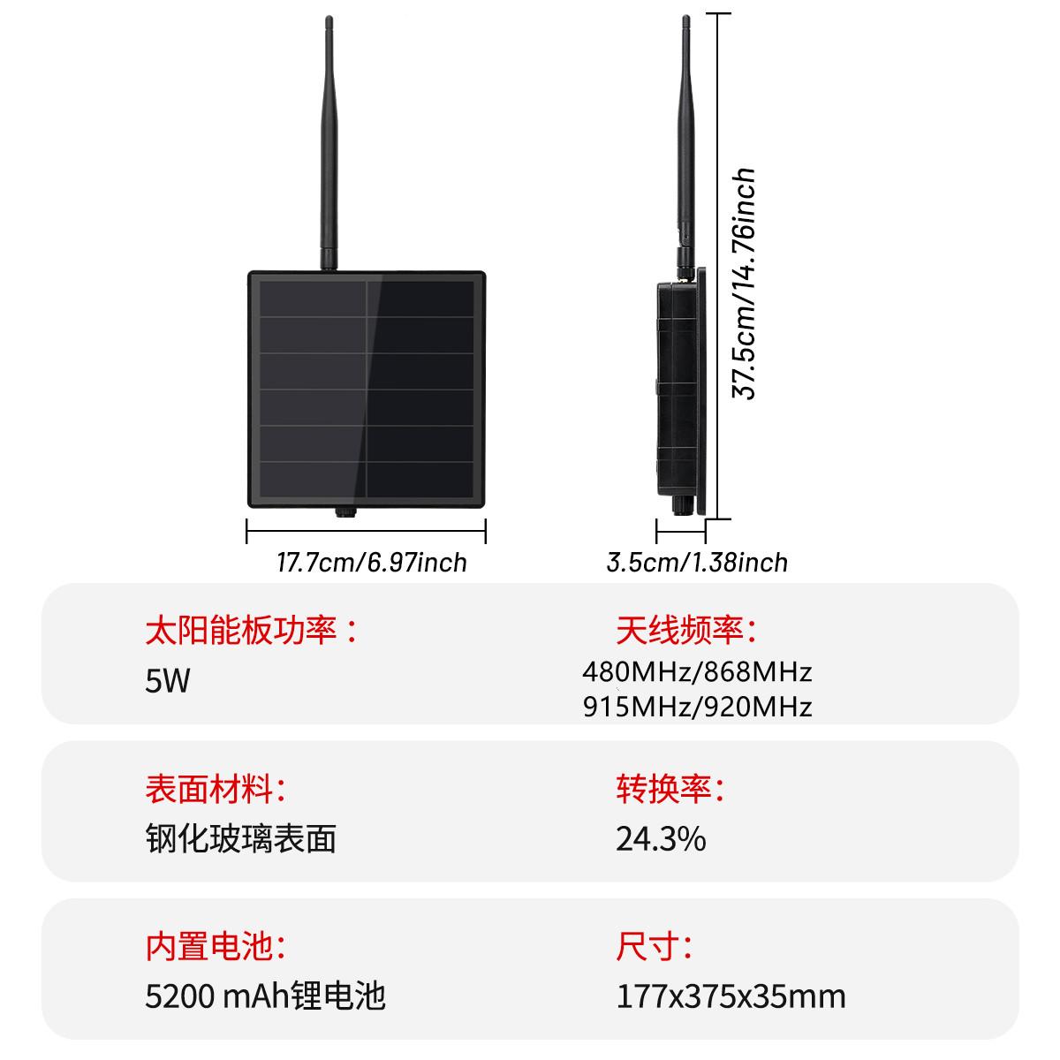
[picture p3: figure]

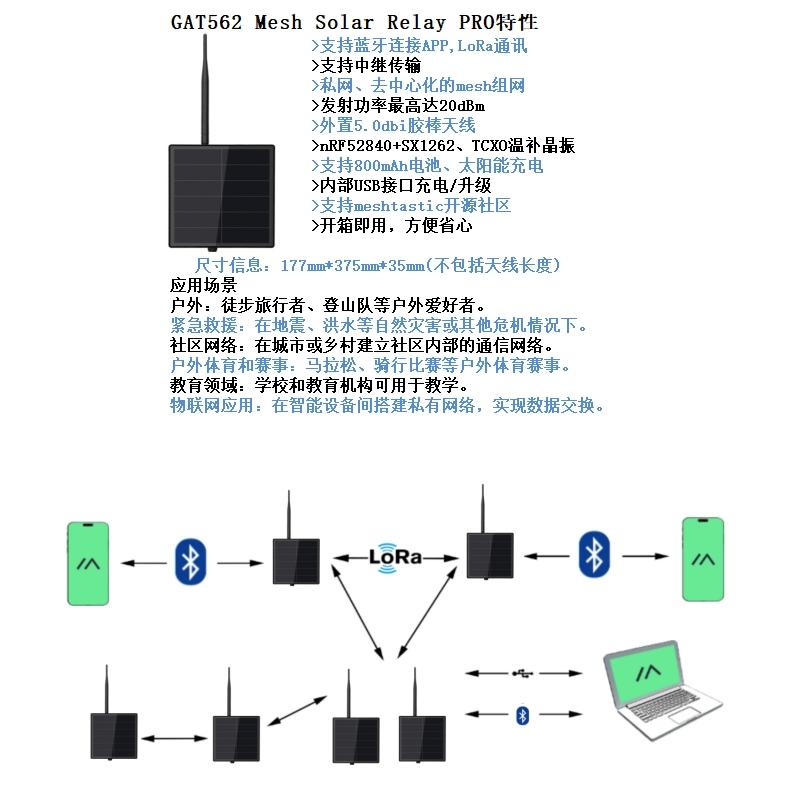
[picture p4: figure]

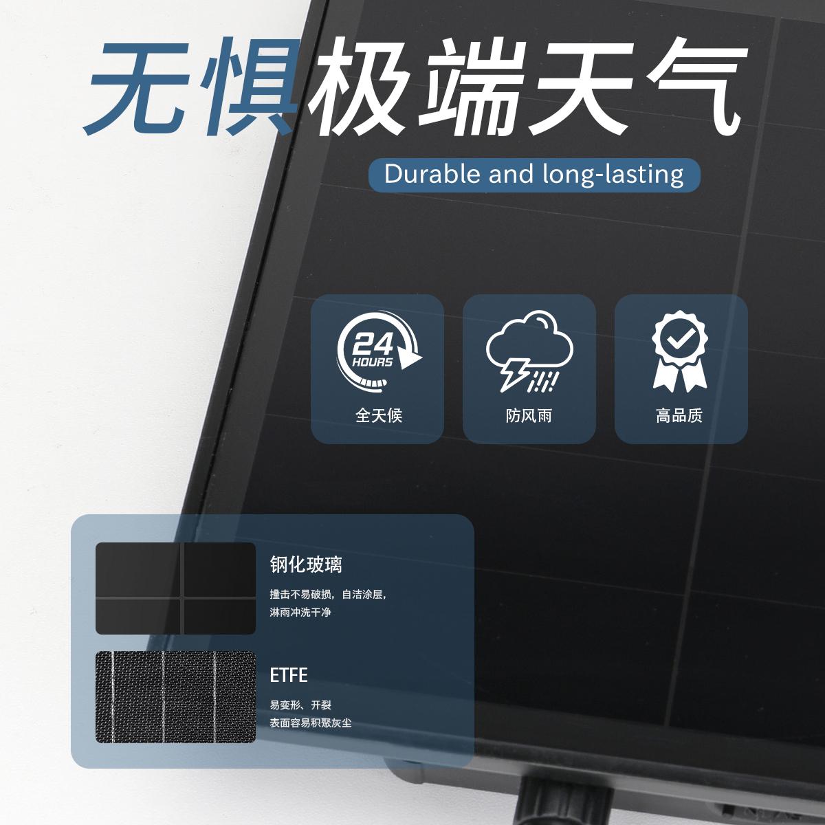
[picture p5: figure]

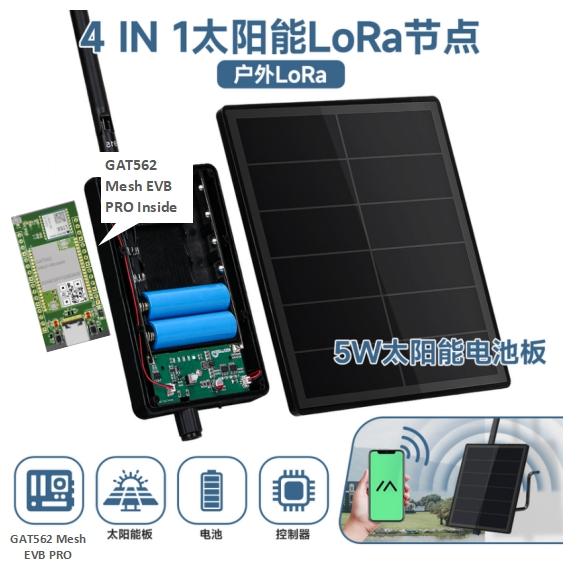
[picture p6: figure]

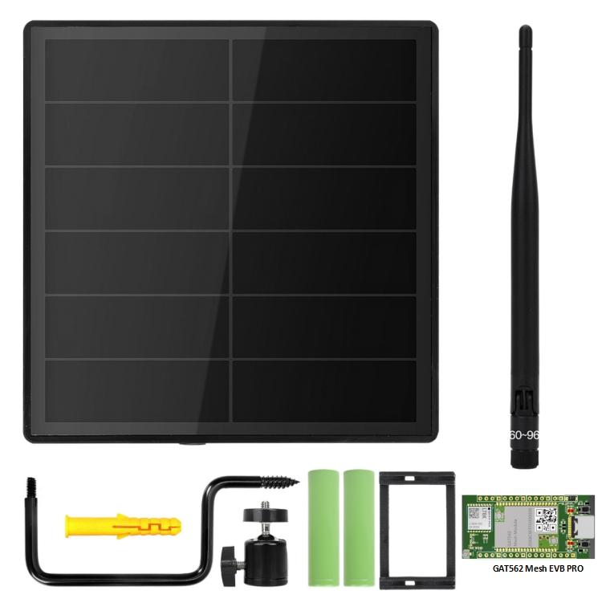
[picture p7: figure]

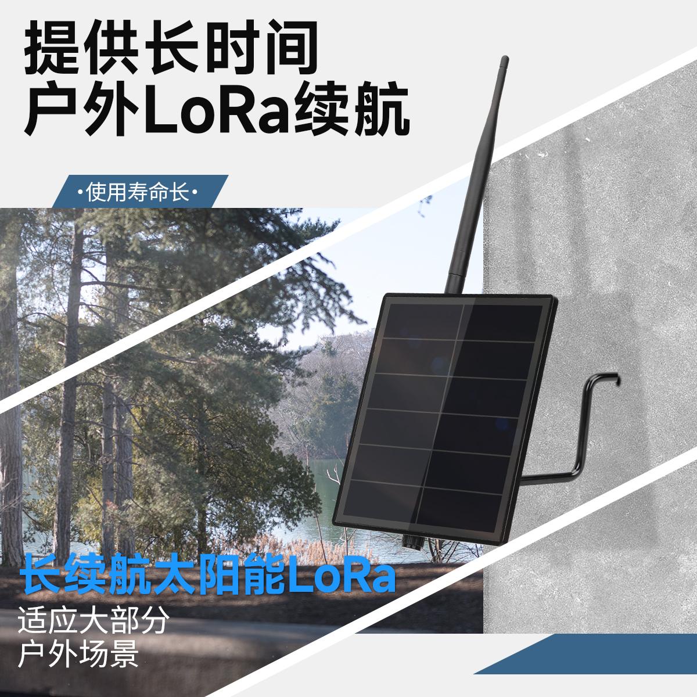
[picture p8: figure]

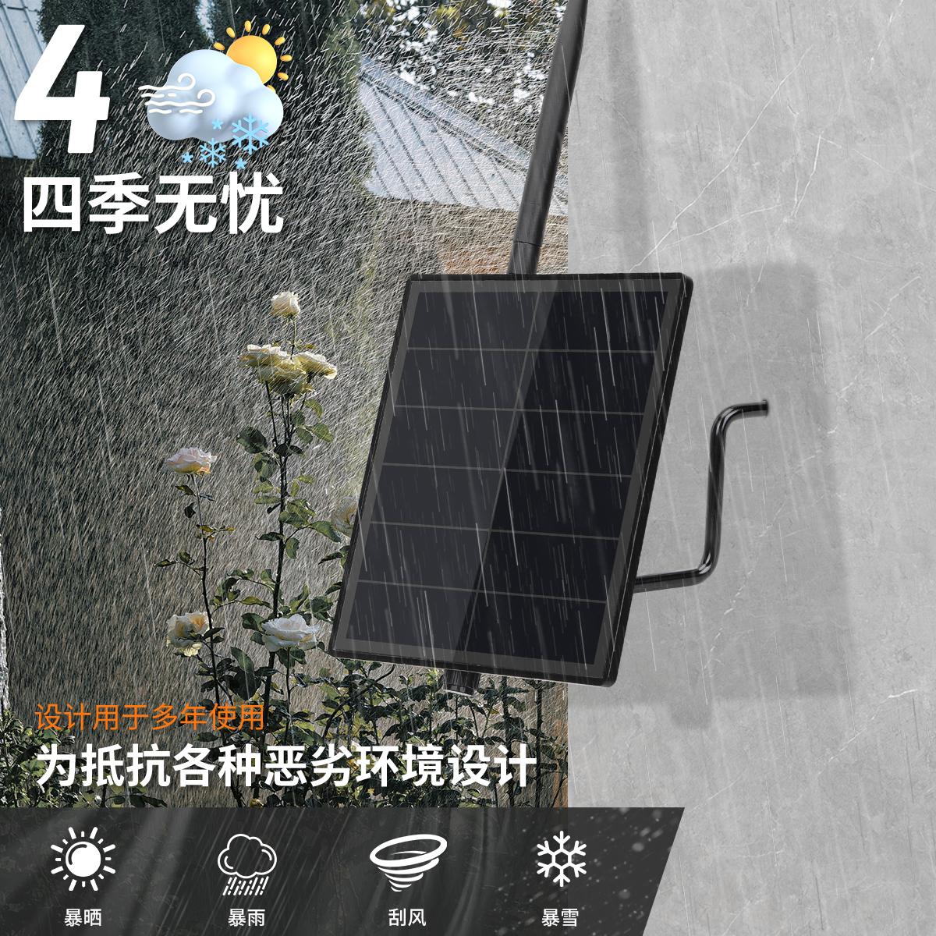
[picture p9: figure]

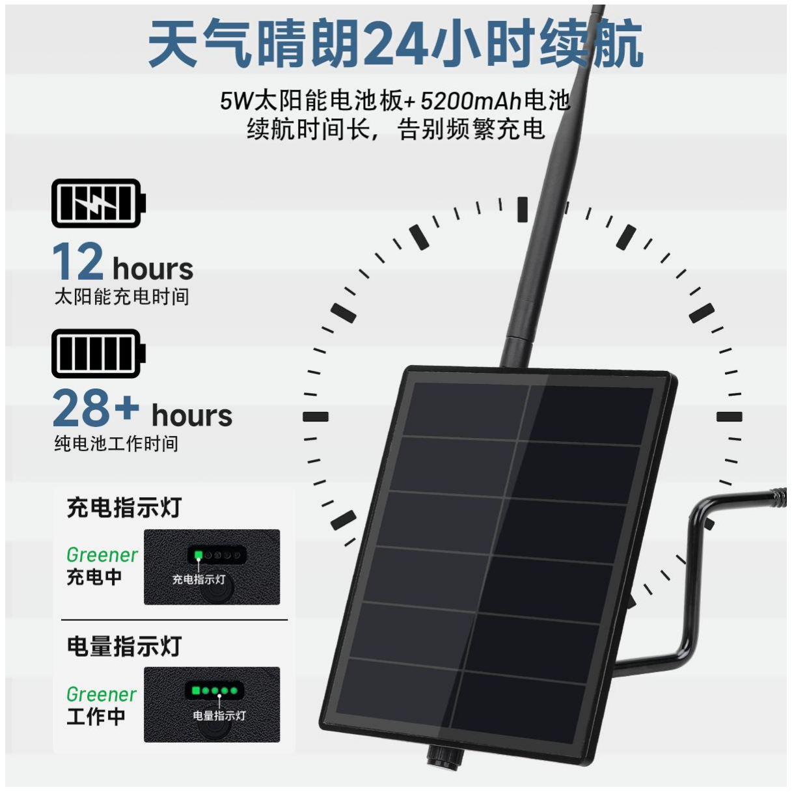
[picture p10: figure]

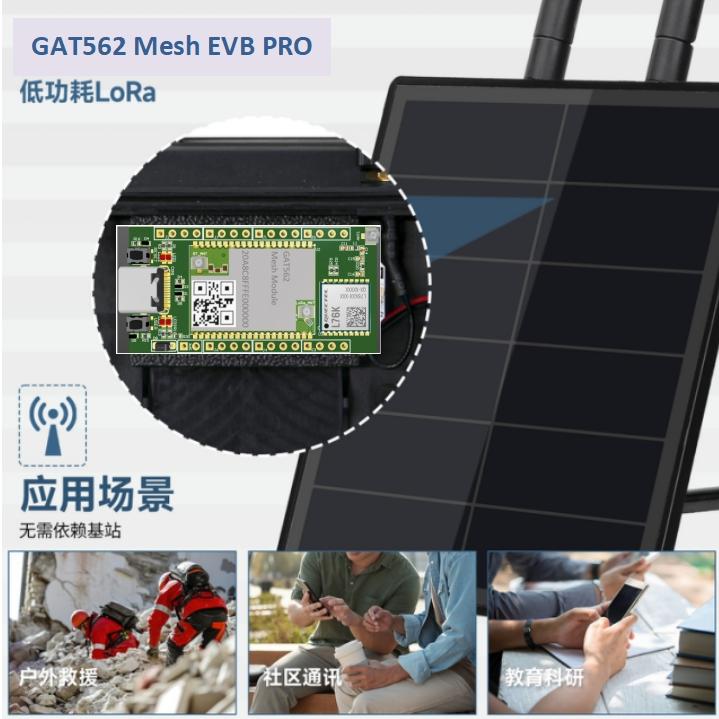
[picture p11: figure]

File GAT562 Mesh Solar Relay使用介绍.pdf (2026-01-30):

# GAT562 Mesh Solar Relay 使用介绍

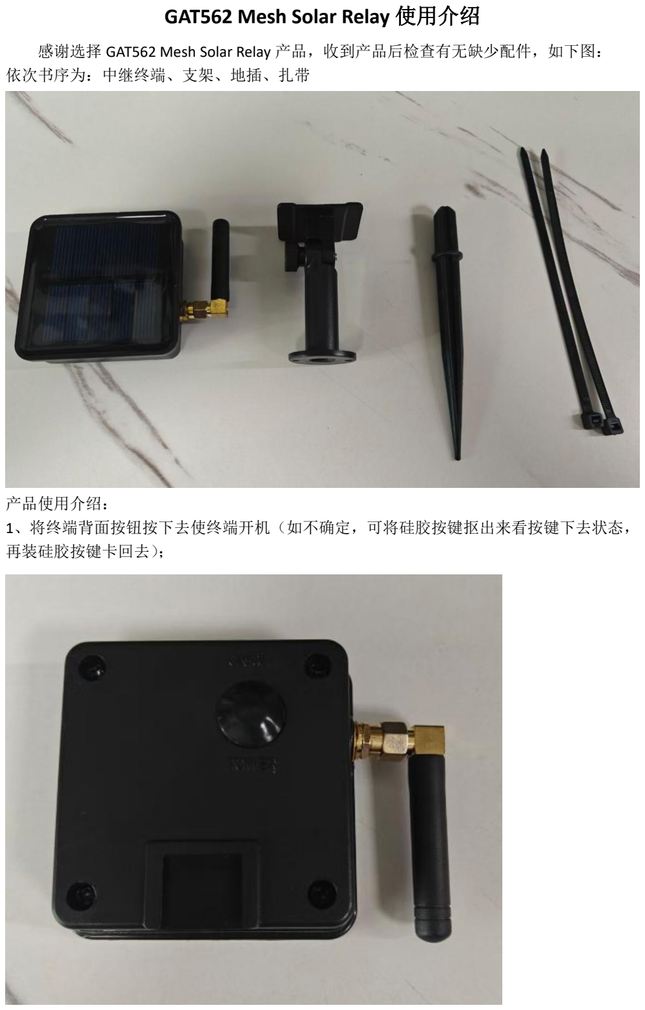
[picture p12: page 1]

感谢选择 GAT562 Mesh Solar Relay 产品，收到产品后检查有无缺少配件，如下图： 依次书序为：中继终端、支架、地插、扎带

产品使用介绍：
1、将终端背面按钮按下去使终端开机（如不确定，可将硅胶按键抠出来看按键下去状态， 再装硅胶按键卡回去）；

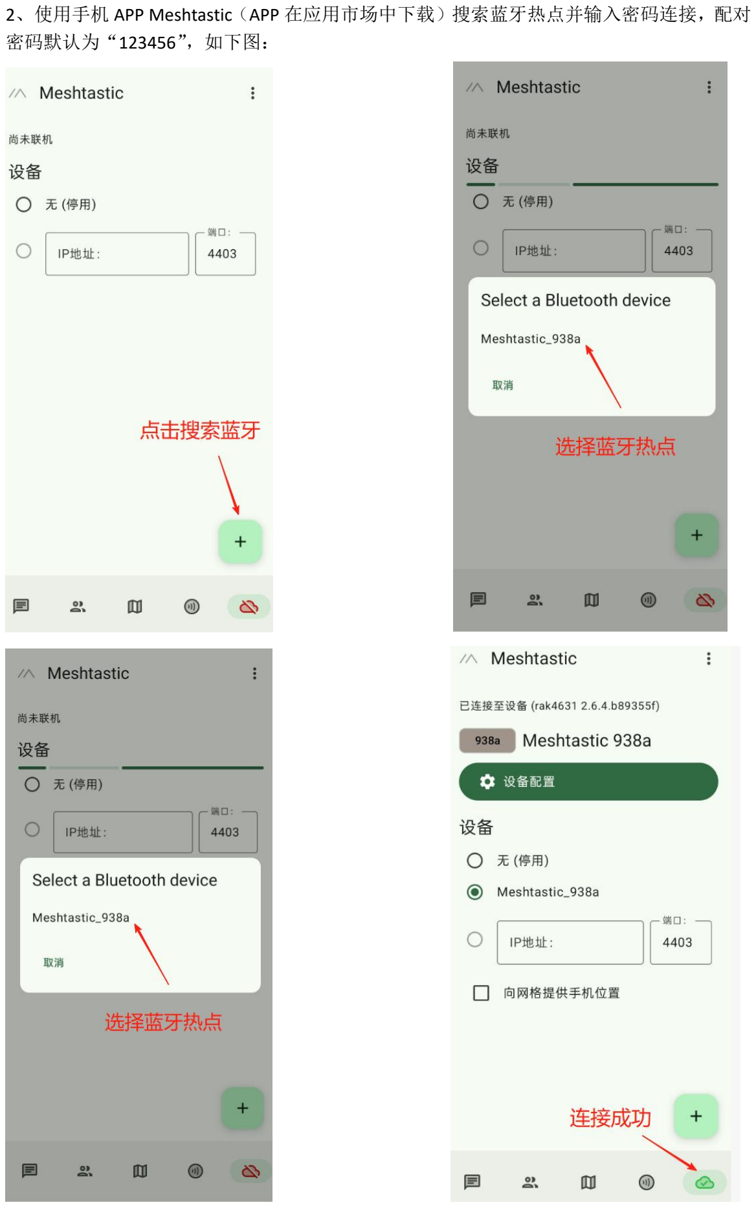
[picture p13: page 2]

2、使用手机 APP Meshtastic（APP 在应用市场中下载）搜索蓝牙热点并输入密码连接，配对 密码默认为“123456”，如下图：

3、设置电池 ADC 采样系数为 1.75，点击设备配置、点击电源、输入 ADC 系数为 1.75 点击 传送，终端将重启生效；

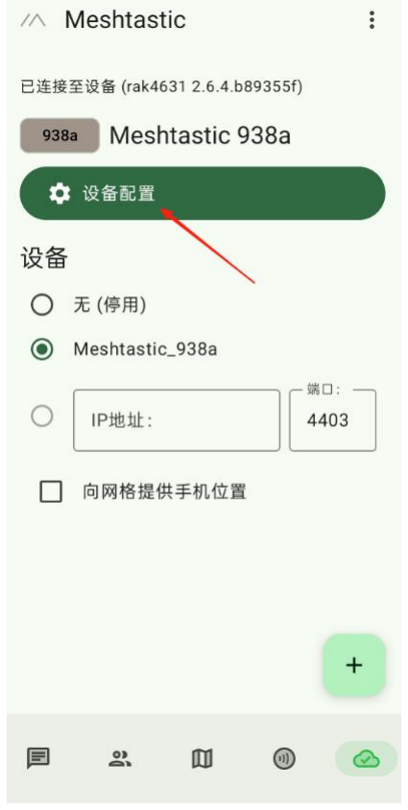
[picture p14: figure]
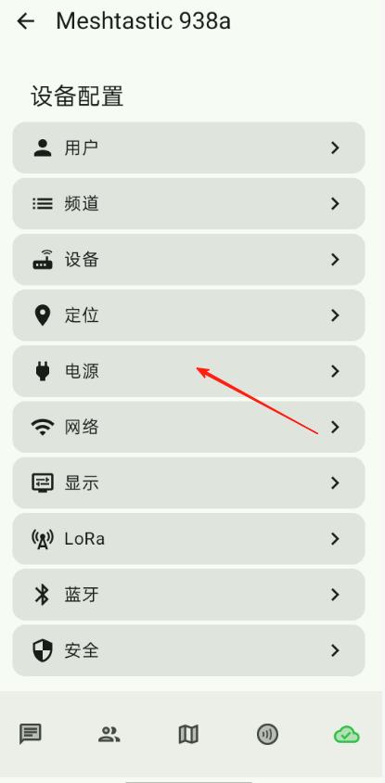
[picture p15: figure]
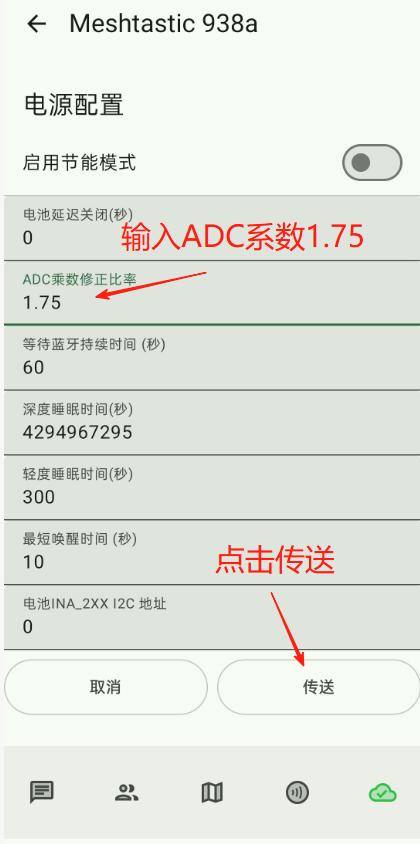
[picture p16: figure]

4、设置终端固定位置，点击设备配置、点击定位、点击传送，输入需要放置位置的经纬度 与高度，点击传送，终端将重启生效；

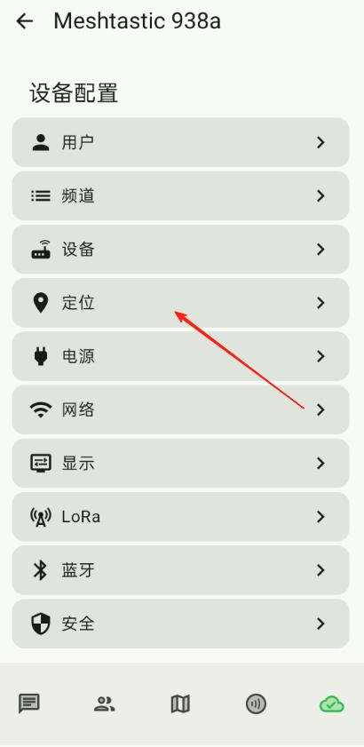
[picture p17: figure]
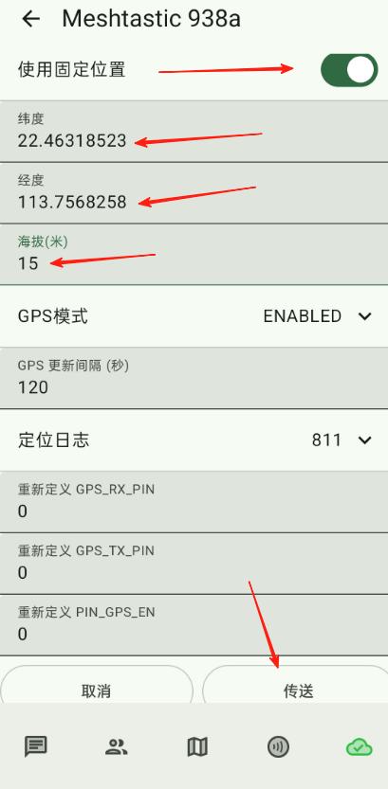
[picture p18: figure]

5、以上设置完成后将直接卡到终点背面卡槽内，地插与直接对插好，固定安装到户外露天 位置，这样才能保障电池每天都能进行太阳能充电，因为内置电池容量 800mA，只能使用 80H 左右，务必安装在露天位置，否则电池电池将很快耗尽，依靠太阳能充电很难充满。 露天位置安装参考，务必将终端倾斜 30-40 度左右安装，这样在下雨天气雨水将顺着斜度流 下，如有条件的情况下建议将外壳打胶一圈，增加防水等级。

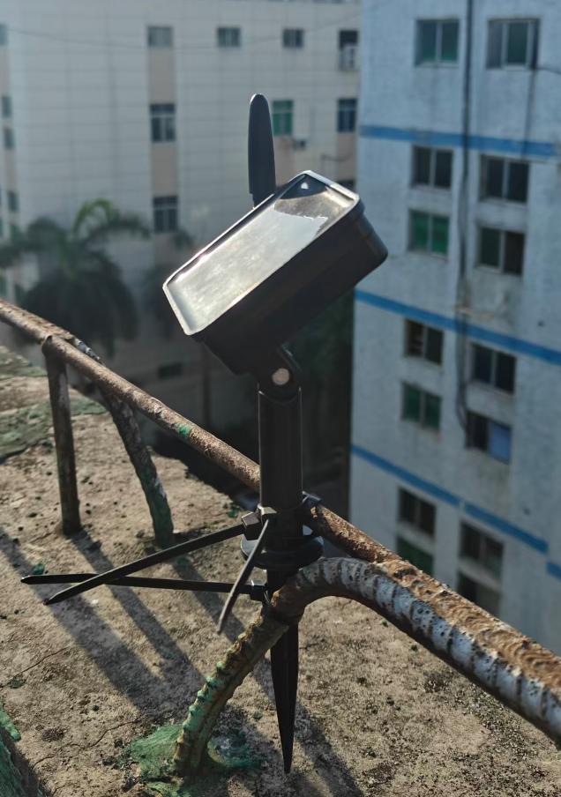
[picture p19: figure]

6、如出现电池电量耗尽或者需要更新固件，需要将外壳拆开，使用 USB 线焊接到排针孔上 进行充电或者更新固件，接线示意图如下：
R:5V（红线对应接 5V）
W:DN（白线对应接 DN）
G:DP（绿线对接接 DP）

## B:GND(黑线对应接 GND) TP:RESET（复位测试点）

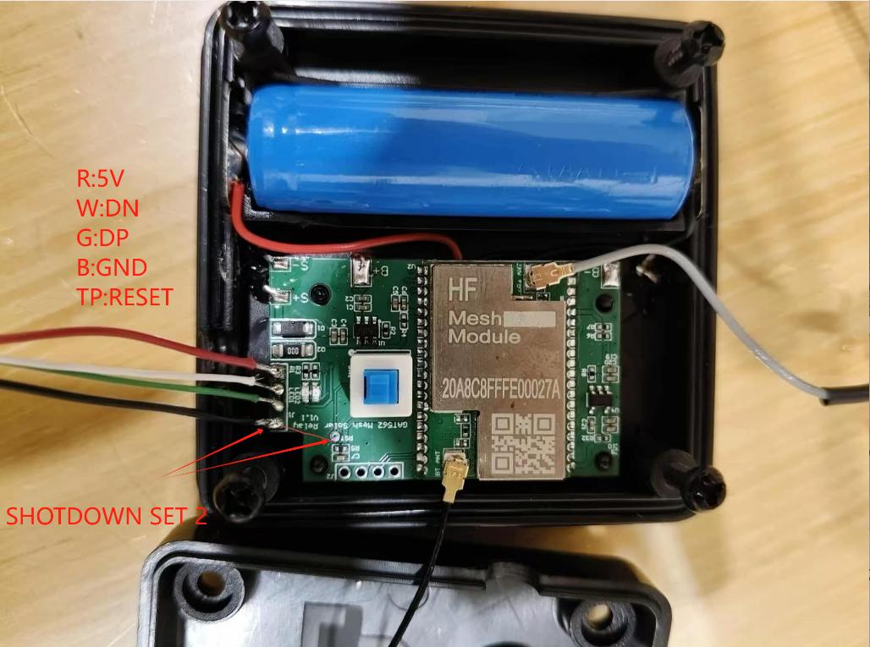
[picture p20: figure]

接线完成后将数据线连接到电脑，使用镊子一端接 GND，一端接测试点，连续短接两下， 电脑将出现盘符，将需要更新的固件复制粘贴到盘符里面等待完成后自动重启生效。

## 固件升级参考链接：https://meshcn.net/gat-iot-handheld-flash-meshtastic-firmware/ 网页配置链接：https://client.meshtastic.org/ 固件升级链接：https://flasher.meshtastic.org/

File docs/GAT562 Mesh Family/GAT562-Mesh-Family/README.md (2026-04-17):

---
 GAT562 Mesh 产品系列官方文档中心。GAT562 基于 Nordic nRF52840 + Semtech SX1262 设计，与 RAK4631 模组 IO 完全兼容，支持 Meshtastic 开源固件和 LoRa/BLE 5.0 双模通信。
 /assets/images/wisblock/gat562/GAT562-family.png

 prev
 ../
 next
 ./GAT562-Mesh-Module/
 gat562
 meshtastic
 lora
 nrf52840
 sx1262

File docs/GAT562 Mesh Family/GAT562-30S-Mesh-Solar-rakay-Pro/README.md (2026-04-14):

# GAT562 30S Mesh Solar rakay Pro

## 产品简介

GAT562 30S Mesh Solar rakay Pro 是 GAT562 家族的**旗舰级太阳能中继方案**，搭载 **30 dBm（1 W）高功率模组** + 大容量太阳能供电系统，专为超远距离 Mesh 网络中继设计，是楼顶固定中继站的终极选择。

## 核心配置

| 组件 | 规格 |
|---|---|
| **LoRa 模组** | GAT562 30S Mesh Module（**30 dBm 高功率**）|
| **中继类型** | 高功率 |
| **发射功率** | 30 dBm（1 W）|
| **通信距离** | 15 km+（开阔地）|
| **太阳能板** | 大面积（≥ 10W 推荐）|
| **锂电池** | 大容量（≥ 10000 mAh 应对阴天）|
| **天线** | 高增益全向/定向天线（≥ 5dBi）|
| **安装高度** | 越高越好（最佳位置：楼顶中央）|

## 为什么选择 30S 高功率中继？

| 对比项 | 22 dBm 中继 | **30 dBm 中继** |
|---|---|---|
| 覆盖半径 | 8-15 km | **15-30+ km** |
| 穿透力 | 一般 | **强（适合山区）** |
| 中继跳数 | 3-5 跳 | **8-10+ 跳** |
| 适用地形 | 平原/郊区 | **山区/海上/开阔地** |
| 功耗 | 较低 | 较高（但太阳能可弥补）|

## 部署建议

> ⚠️ **法规注意**：30 dBm 在部分地区使用时需遵守当地无线电法规（占空比限制、天线增益限制等）。

**最佳部署实践：**
1. **选址**：楼顶中央制高点，天线高于周边障碍物
2. **天线**：使用 ≥ 5dBi 全向天线，或定向天线（点对点场景）
3. **供电**：太阳能板朝南（北半球），倾角与当地纬度相同
4. **防护**：使用防水外壳（IP67），避免雨水进入
5. **配置**：Meshtastic 中继模式，设置合适的跳频参数

## 相关文档

- [GAT562 30S Mesh Module 数据手册 →](../GAT562-30S-Mesh-Module/Datasheet/)
- [快速入门 →](../GAT562-30S-Mesh-Module/Quickstart/)
- [Meshtastic 官方](https://meshtastic.org)
- [GitHub 资源](https://github.com/gat-iot/GAT562-family)

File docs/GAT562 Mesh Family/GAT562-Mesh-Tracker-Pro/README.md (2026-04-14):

# GAT562 Mesh Tracker Pro

## 产品简介

GAT562 Mesh Tracker Pro 是一款基于 GAT562 Mesh Module 的手持 Meshtastic 终端设备，预装 Meshtastic 开源固件，开箱即用，适合随身携带进行 Mesh 网络通信。

## 核心配置

| 组件 | 型号/规格 |
|---|---|
| **LoRa 模组** | GAT562 Mesh Module（22 dBm） |
| **主芯片** | nRF52840 + SX1262 + TCXO |
| **显示屏** | 1.3" TFT（可选配） |
| **定位** | GPS 模块接口（UART） |
| **输入** | 按键 / 摇杆 |
| **指示** | LED / 蜂鸣器 |
| **供电** | 内置锂电池 |
| **通信** | LoRa Mesh + BLE 5.0 |

## 典型应用

- 📍 **位置共享**：实时将自己的 GPS 位置广播到 Mesh 网络
- 💬 **文字消息**：无网络环境下与队友互发文字消息
- 🚶 **组队出行**：野外徒步、骑行、登山团队的离网通信
- 🏕️ **户外探险**：没有手机信号的偏远地区通信保障
- 🚨 **应急通信**：灾害现场的临时通信保障

## 功能特点

- ✅ **去中心化 Mesh**：无需基站，每个设备都是中继节点
- ✅ **位置追踪**：GPS 实时定位，支持地图显示
- ✅ **消息加密**：AES256 端到端加密
- ✅ **低功耗设计**：nRF52 架构，持久续航
- ✅ **中文界面**：Meshtastic App 支持中文

## 相关文档

- [Meshtastic 官方](https://meshtastic.org)
- [GAT562 Mesh Module 概述 →](../GAT562-Mesh-Module/Overview/)
- [GitHub 资源](https://github.com/gat-iot/GAT562-family)

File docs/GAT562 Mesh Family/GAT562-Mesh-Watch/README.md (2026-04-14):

# GAT562 Mesh Watch

## 产品简介

GAT562 Mesh Watch 是一款可穿戴形态的 Meshtastic Mesh 通信终端，将 GAT562 Mesh Module 集成于手表形态的机身中，专为需要随身通信又不希望携带独立设备的用户设计，适合户外运动、可穿戴追踪等场景。

## 核心配置

| 组件 | 型号/规格 |
|---|---|
| **LoRa 模组** | GAT562 Mesh Module（22 dBm） |
| **主芯片** | nRF52840 + SX1262 + TCXO |
| **显示屏** | 手表屏幕（1.x" TFT） |
| **定位** | GPS 模块（可选） |
| **传感器** | 加速度计等运动传感器（依批次） |
| **供电** | 内置锂电池 |
| **通信** | LoRa Mesh + BLE 5.0 |

## 典型应用

- 🏃 **运动追踪**：跑步、骑行时的位置共享与通信
- ⛰️ **户外运动**：轻量级离网通信
- 👥 **团队联络**：无需掏出手机，快速收发消息
- 📍 **位置监控**：家人/队友之间实时位置共享

## 相关文档

- [GAT562 Mesh Module 概述 →](../GAT562-Mesh-Module/Overview/)
- [Meshtastic 官方](https://meshtastic.org)
- [GitHub 资源](https://github.com/gat-iot/GAT562-family)

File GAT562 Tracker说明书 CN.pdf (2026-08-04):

## GAT562 Tracke 说明书

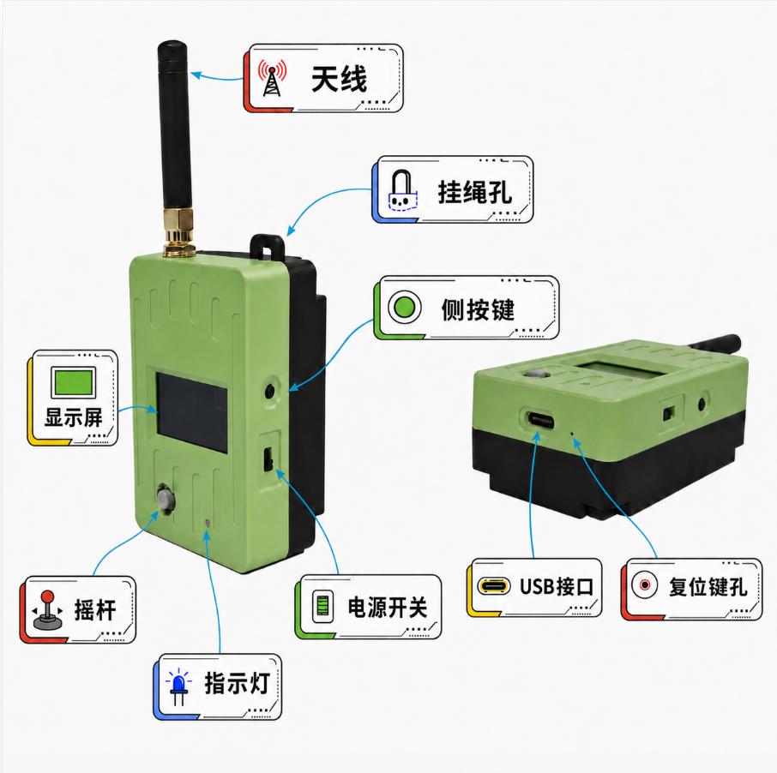
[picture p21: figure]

产品信息
型号 | GAT562 Tracker XXXX
类型 | 手持终端 | 外壳尺寸 | 70*48*28mm
通讯协议 | Meshtastic | 外壳材质 | ABS
充电电源 | DC 5V——2A | 充电接口 | TYPE C

下载 APP
Android 版本:
从 Play Store 应用中搜索 meshtastic 进行下载 iOS 版本：
从 APP Store 应用中搜索 meshtastic 进行下载

功能介绍
天线 | 信号收发
挂绳孔 | 挂绳/挂扣
显示屏 | UI/菜单/功能列表/信息显示
侧按键
开机模式下 | 按一下息屏
长按弹出功能栏 | 按一下切换 | 长按选择对应功能
长按 8S 以上松开后关机
电源开关 | 开关向上时关机
开关向下时开机

摇杆

上：向上推动
下：向下推动
左：向左推动
右：向右推动
确认：按下中间按键

指示灯

蓝灯：收到信息后闪烁
翠绿灯：待机模式下闪烁
红灯：充电时常亮
绿灯：充满电时亮
USB 接口 | 充电/下载固件
复位键孔 | 按一下复位
连续按 2 下进入 boot loader 模式

使用介绍：
1. 按下“电源开关”使终端开机，等待 30S 左右系统加载完成，拨动摇动左右 切换界面；
2. 在对应的界面按下摇杆中间按键，将弹出对应的功能选项，可根据需求选择 对应的功能进行设置；
3. 通过摇杆切换界面到时钟显示界面，按下摇杆中间键，弹出时区设置，通过 摇杆上下键切换对应的时区，选择所在地区时区按摇杆中间键选择确认；
4. 使用手机打开 meshtastic APP 连接手表蓝牙热点，输入显示屏显示密码，手表 将自动同步时间；

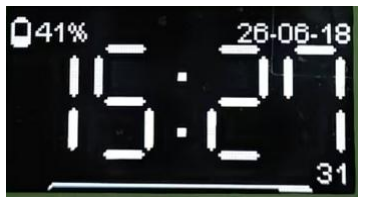
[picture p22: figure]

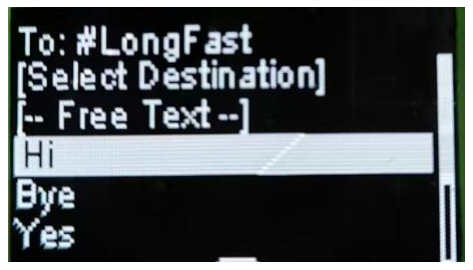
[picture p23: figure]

发送预设消息介绍

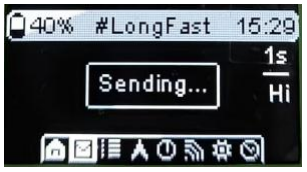
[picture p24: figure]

在 UI 主界面下拨摇杆进入信息页面，通过摇杆上下键选择需要发送的消息，按 下摇杆中间键发送，发送后界面将显示发送状态；

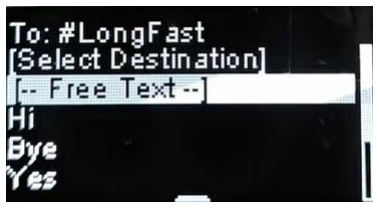
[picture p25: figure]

发送自定义消息介绍

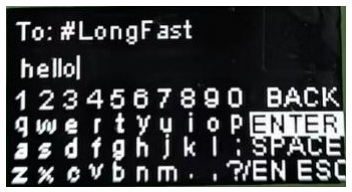
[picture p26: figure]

在 UI 主界面下拨摇杆进入信息页面，通过摇杆键选择 Free Text 按摇杆中间键进 入虚拟键盘，通过摇杆上下左右键入信息，通过摇杆选择 ENTER 按键摇杆中间 键发送，发送后界面将显示发送状态；


中英文输入切换


在虚拟键盘页面中按一下侧按键切换 EN 或 CN，EN 为英文输入状态，CN 为中文输入状态；

GPS 定位介绍
GPS 需要在户外露天位置才能搜星并定位，定位成功后将显示卫星数量与经纬度和海拔高度 也可通过摇杆选择关闭 GPS 功能，在 Positong 界面按键摇杆中间键，选择 On/Off Toggle-选
择 Disable，将显示 GPS off；



连接手机 APP 使用介绍（介绍为安卓 APP）
1.点击扫描按钮，选择对应设备的蓝牙热点，输入终端显示屏显示的密码点保存，APP 将与 设备连接成功；
2. 设备连接 APP 后可在 APP 上操作收发信息、查看同频道的设备列表、地图位置、终端设 置等等；


设备升级介绍


使用数据线将设备与电脑连接好，使用回形针插入复位孔连续按 2 下，此电脑中将显示
GAT562_BOOT，选择 GAT562_BOOT 进入磁盘根目录，将 GAT562 XXXXXXXXX.uf2 固件复制粘
贴到磁盘根目录将自动完成升级，等待设备重启即完成固件更新；

装箱清单; 保修条款 除人为因素，本产品保修半年; --------------------------------------------------------------------------------------------------------------------------------- 保修卡; --------------------------------------------------------------------------------------------------------------------------------- 保修卡需按虚线裁剪下来; 合格证 --------------------------------------------------------------------------------------------------------------------------------- 合格证; QUALIFIED CERTIFICATE; 检验员：

序号 | 名称 | 数量
1 | 终端主机 | 1
2 | 数据线 | 1
3 | 胶棒天线 | 1
4 | 卡扣 | 1

客户姓名 | 联系电话

联系地址

购买日期 | 代理商名称

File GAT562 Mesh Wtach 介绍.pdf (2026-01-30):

户外运动爱好者专属！

## GAT562 Mesh Watch 震撼登场，重塑户外 meshtastic 通信体验！

户外运动爱好者们，当你踏上徒步旅行的小径，攀登巍峨的山峰，或是在马拉松的赛道 上奋力驰骋时，是否曾为通信受阻而烦恼？是否渴望有一款设备，既能成为你的通信助手， 又能完美适配户外运动场景？现在，GAT562 Mesh Watch 来了，它将为你的户外运动之旅带 来前所未有的变革！


Meshtastic 强大组网通信能力，突破户外信号困境 在荒郊野外，手机信号常常微弱甚至全无，而 GAT562 Mesh Watch 凭借其独特的通信 技术，为你搭建起可靠的通信桥梁。它支持蓝牙连接 APP 和 LoRa 技术，还具备中继传输 功能，能轻松组建私网、去中心化的 mesh 组网。无论是在连绵的山脉中徒步，还是在茂 密的丛林里探险，你都能与同伴保持实时联系，分享精彩瞬间，或是在紧急时刻发出求救信 号。发射功率最高达 19dBm，搭配 2.0dbi 天线，信号覆盖范围更广，传输更稳定。nRF52840 + SX1262、TCXO 温补晶振的组合，更是为通信质量保驾护航，让你不再受限于信号问题， 尽情享受户外运动的乐趣。
手表形态，便捷佩戴无负担
GAT562 Mesh Watch 采用经典的手表形态设计，轻巧便携，佩戴起来毫无负担。在户外 运动中，你无需额外携带复杂的通信设备，只需将它戴在手腕上，就能随时使用。无论是攀 岩时双手的腾挪，还是骑行时的风驰电掣，它都能稳稳地陪伴在你身边。而且，它内置震动 马达，当有重要信息传来时，会实时震动提醒，让你在运动的同时也不会错过任何消息，确 保与外界保持紧密联系。


防水耐用，无惧恶劣环境挑战
户外运动往往伴随着各种复杂的天气和环境条件，雨水、汗水、灰尘等都可能对设备造 成损害。但 GAT562 Mesh Watch 内置防水圈，具备 IP65 防水等级，能够轻松应对这些挑 战。无论是在雨中奔跑，还是在溪流边洗手，你都无需担心手表会受损。此外，它还经过了 严格的耐用性测试，能够承受一定程度的碰撞和颠簸，适应各种极端的户外运动场景，为你 的户外之旅提供可靠的保障。
快速交互，一键发送预设信息
在户外运动中，时间就是生命，有时候可能来不及进行复杂的操作。GAT562 Mesh Watch 贴心地配备了 2 个按键，通过简单的配合操作，就可以快速发送预设信息。当你在徒步时 发现美丽的风景想要分享，或是在遇到危险需要紧急求助时，只需轻轻一按，就能迅速传达 你的意图，大大提高了信息传递的效率，为你的安全增添一份保障。 超长续航，持久陪伴每一次征程
内置 800mAh 电池，搭配磁吸充电和 USB 接口充电 / 升级双模式，让 GAT562 Mesh Watch 的续航能力得到了极大的提升。一次充满电，就能满足你长时间的户外运动需求， 无论是多日的徒步旅行，还是高强度的户外赛事，它都能持久陪伴，不会因为电量不足而让 你陷入通信困境。
户外运动爱好者们，GAT562 Mesh Watch 就是为你们量身定制的通信神器！它将强大的 通信功能、便捷的手表形态、出色的防水耐用性以及贴心的交互设计完美融合，让你在户外 运动中能够更加安心、畅快地享受每一刻。别再犹豫，赶紧入手一款 GAT562 Mesh Watch， 开启属于你的全新户外通信时代吧！

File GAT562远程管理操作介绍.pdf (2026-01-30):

GAT562 远程操作管理介绍
1、使用手机 APP 连接 GAT562 管理终端，将管理终端的公钥或者私钥复制保存到手机上， 操作流程——设置——安全——复制公钥——保存到手机上，如下图


2、使用手机 APP 连接需要被管理的 GAT562 终端，进入设置——安全——新增——粘贴复 制好的公钥——传送


3、在 APP 中群组中选择被管理终端，点击终端序列号进入页面下拉选择——远程管理—— 选择需要管理的功能进行修改即可，如下图：

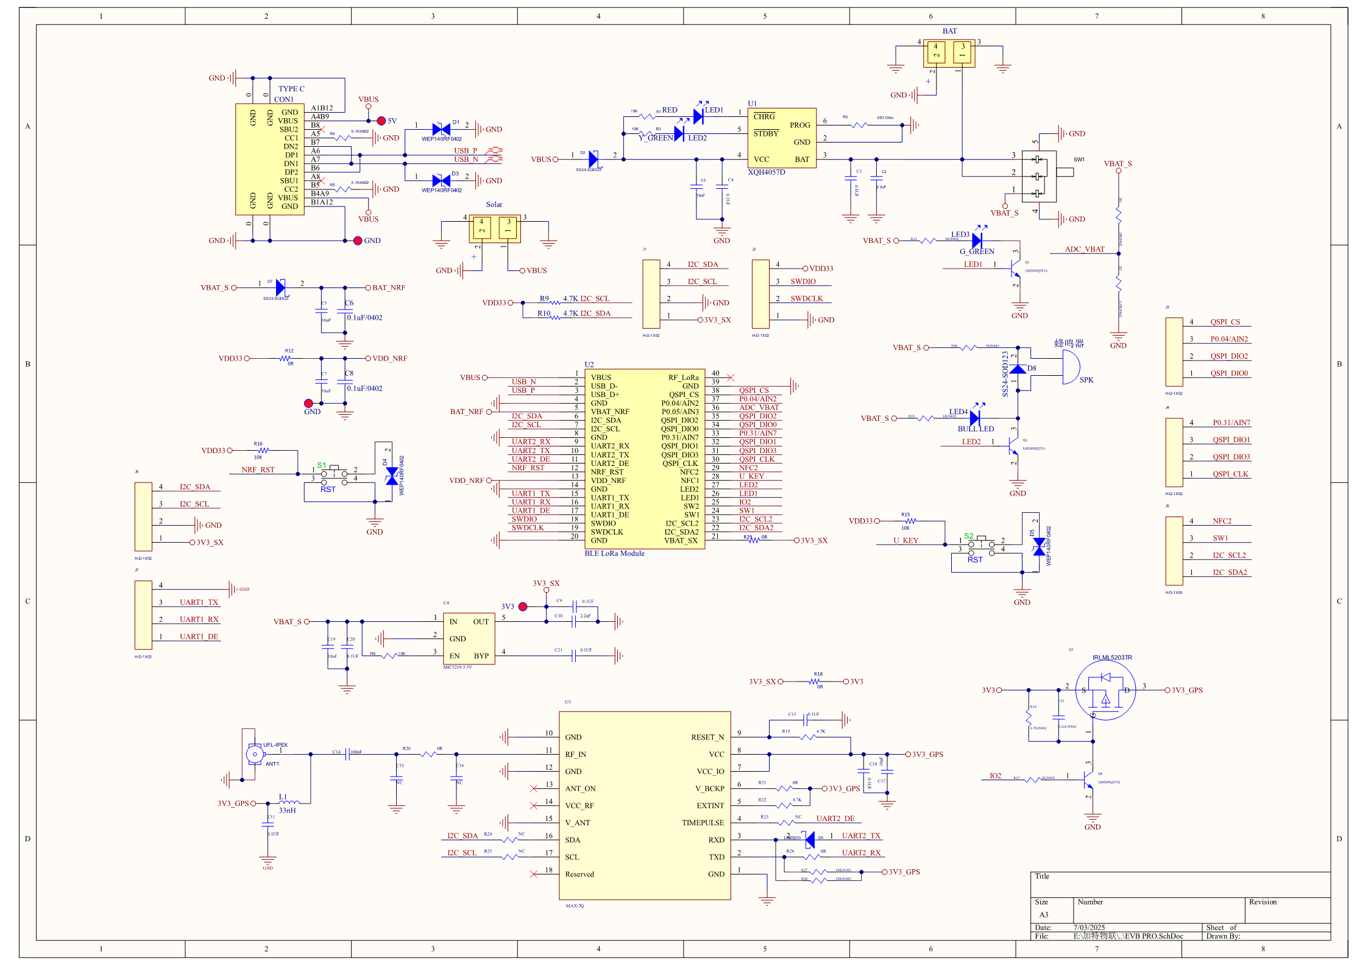
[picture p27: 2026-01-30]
GAT562 Mesh EVB PRO SCH.png

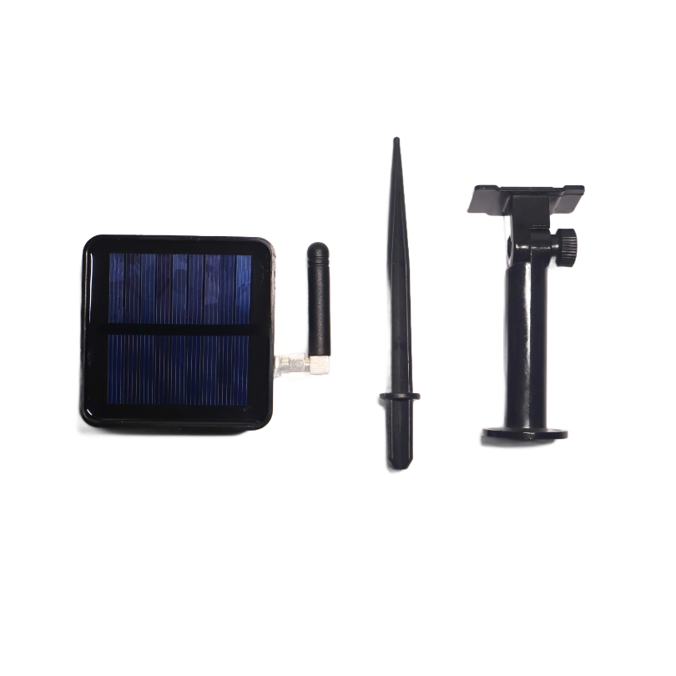
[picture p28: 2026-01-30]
GAT562 Mesh Solar Relay图.png

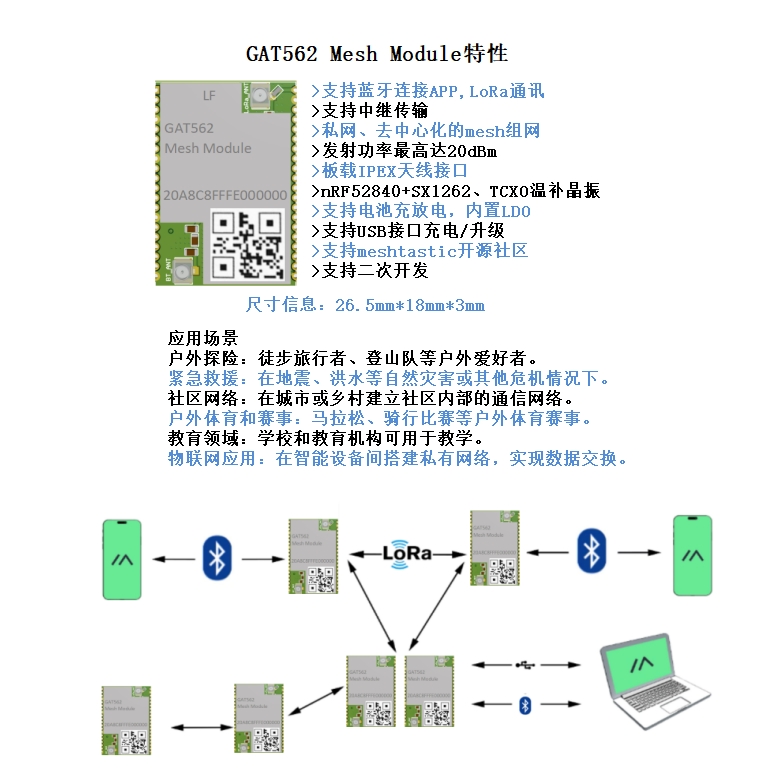
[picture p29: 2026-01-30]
GAT562 Mesh Module 特性图.png

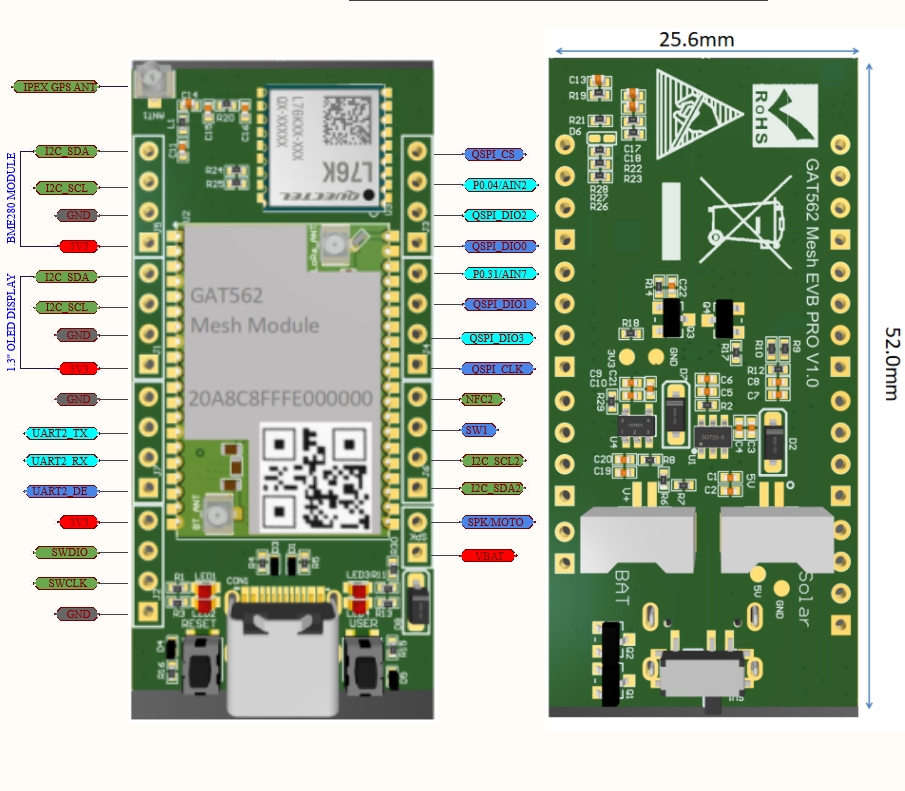
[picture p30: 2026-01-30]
GAT562 Mesh EVB PRO IO.png

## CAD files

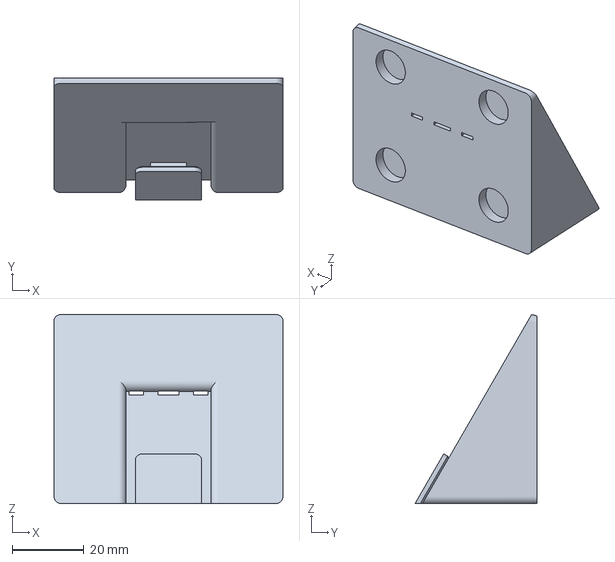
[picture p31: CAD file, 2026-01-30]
GAT562 Mesh Solar Relay支架3D文件.3mf
64.0 x 34.1 x 52.8 mm

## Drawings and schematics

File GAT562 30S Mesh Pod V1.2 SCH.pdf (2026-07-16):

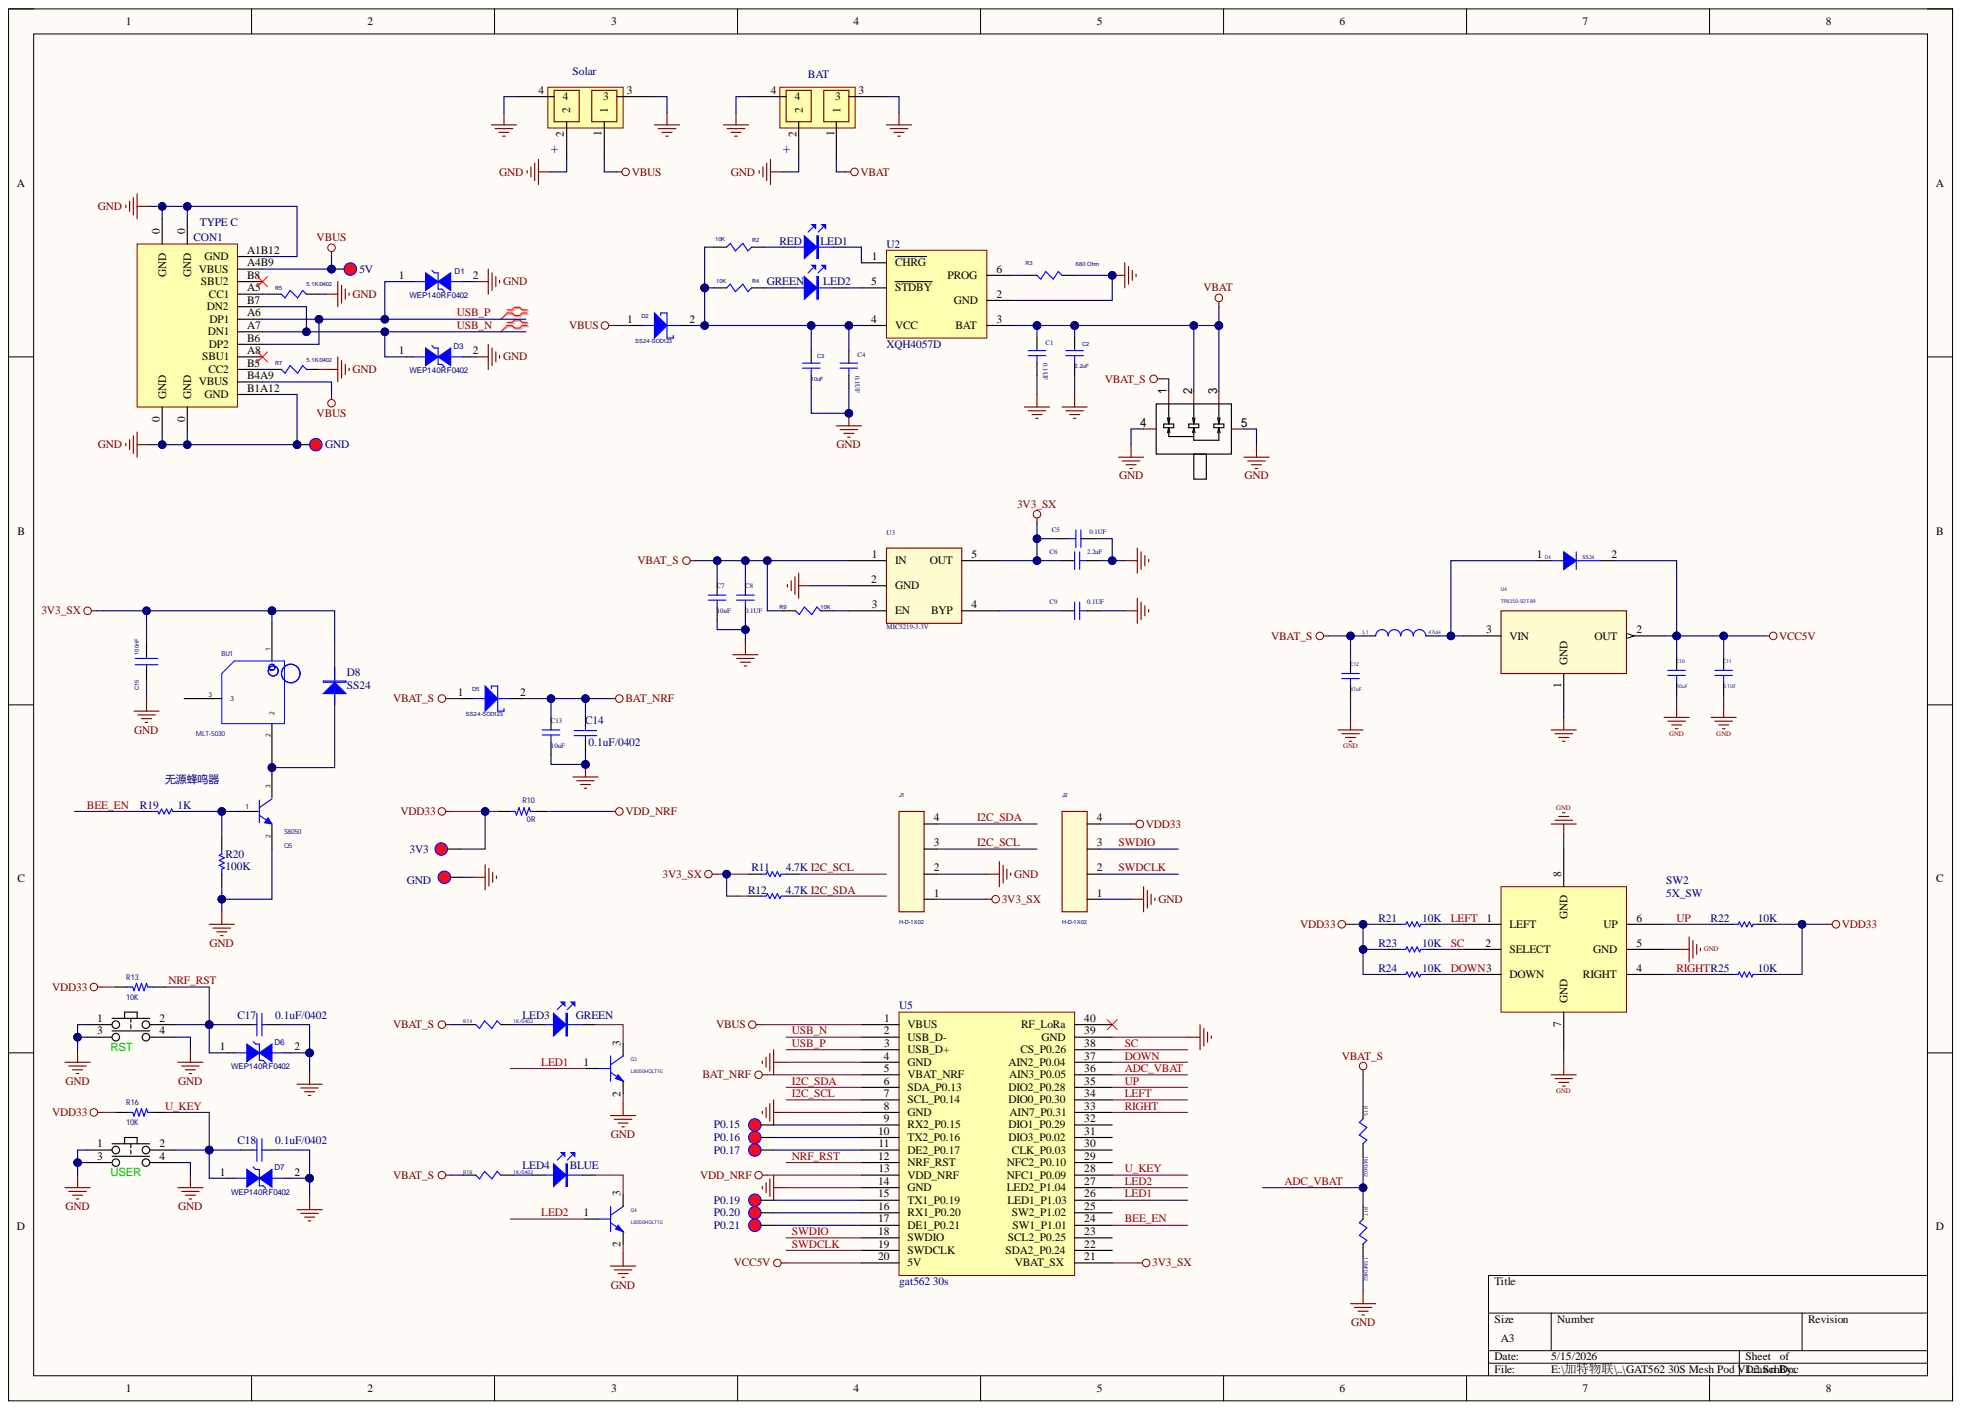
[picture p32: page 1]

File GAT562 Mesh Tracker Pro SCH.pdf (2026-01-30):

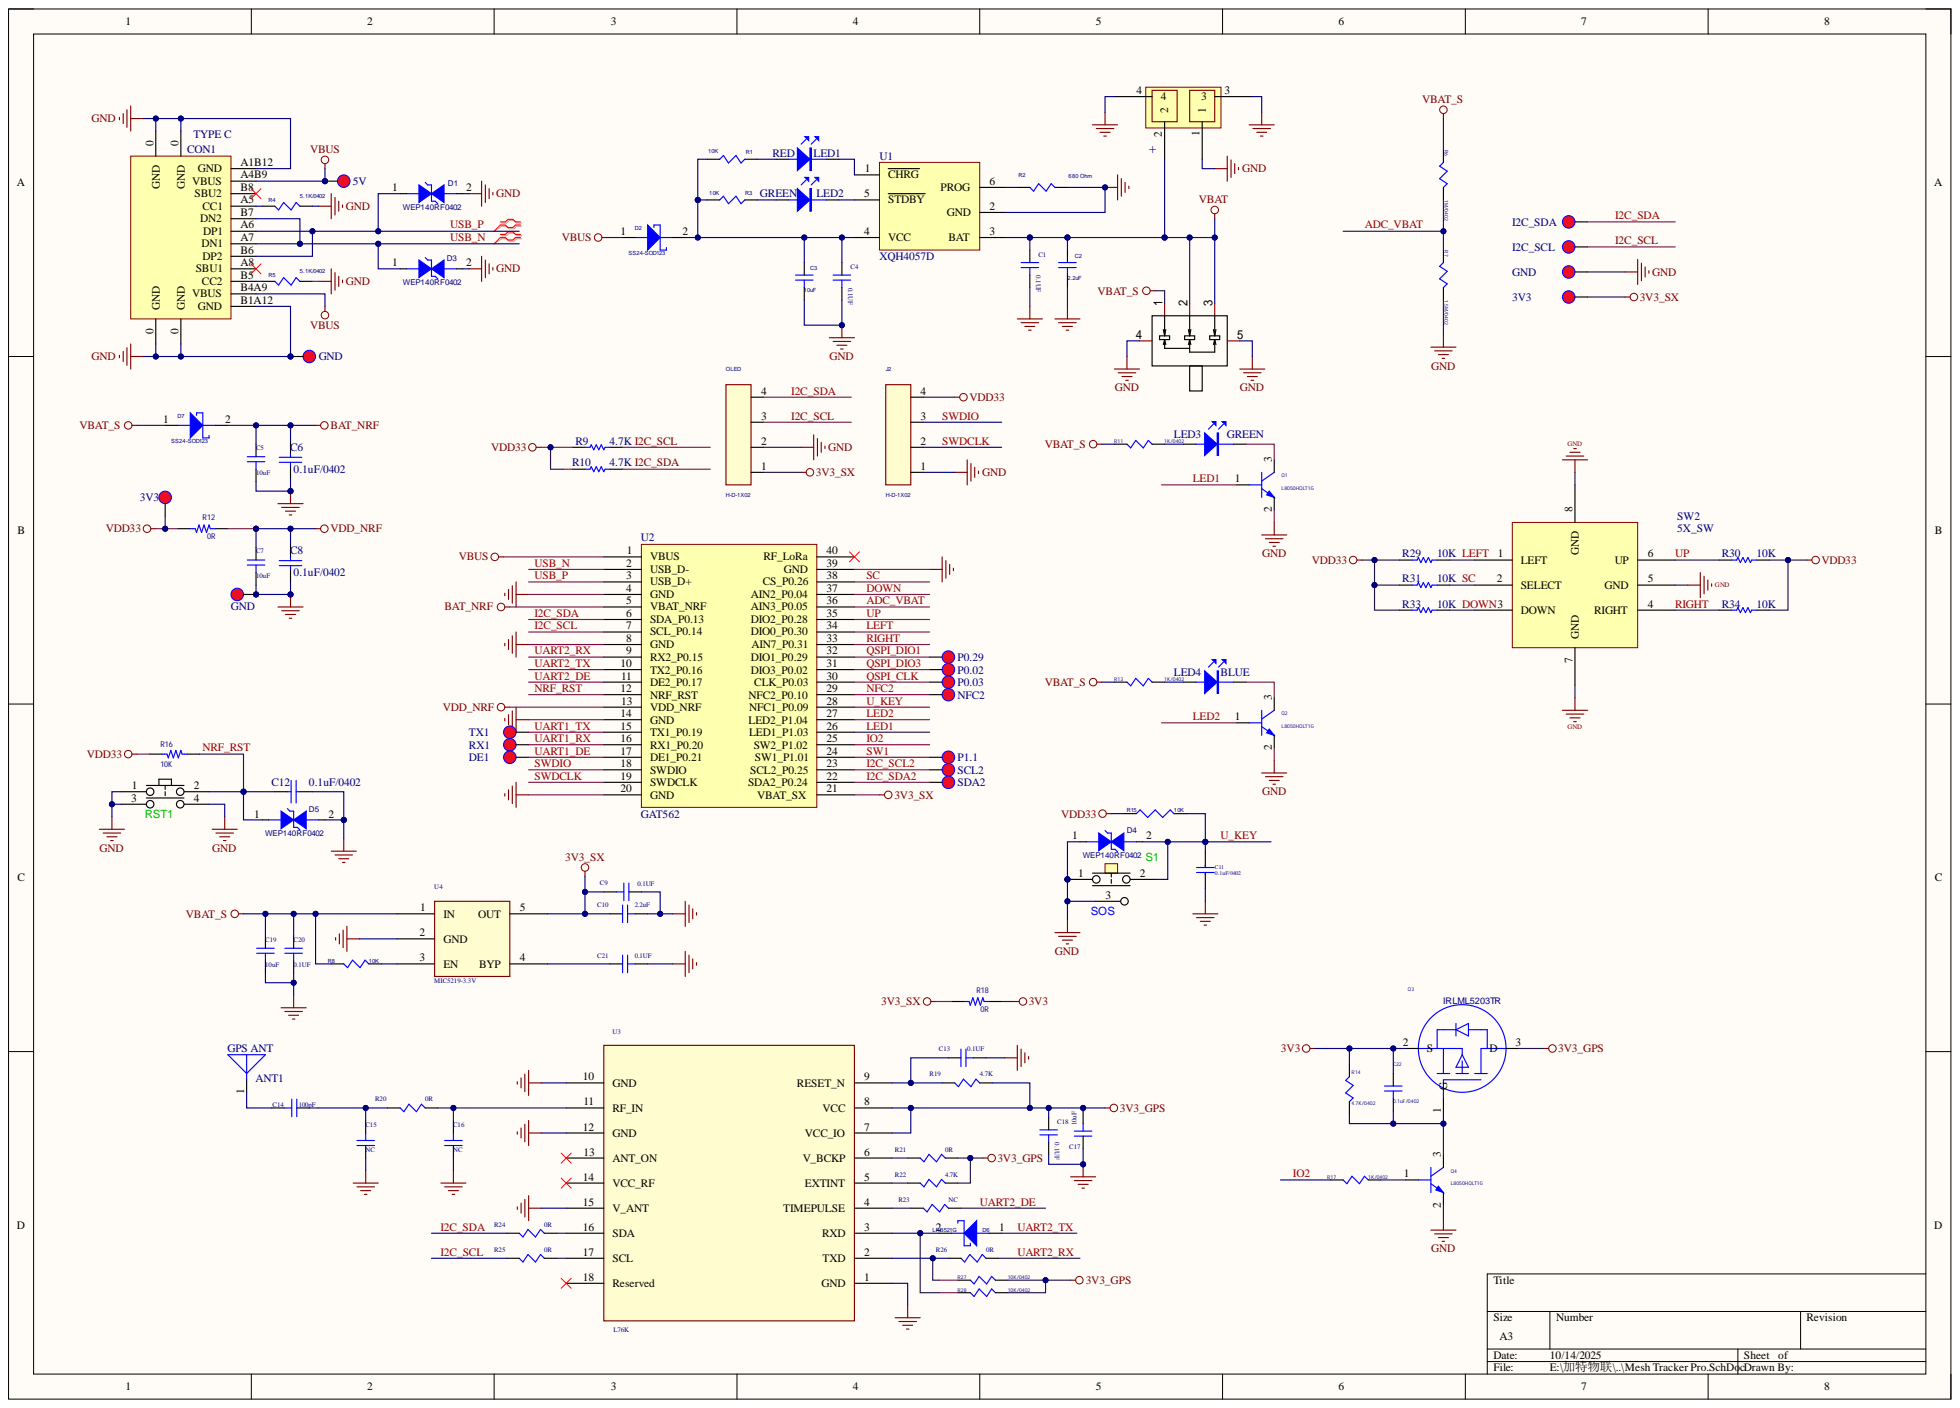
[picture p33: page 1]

TYPE C

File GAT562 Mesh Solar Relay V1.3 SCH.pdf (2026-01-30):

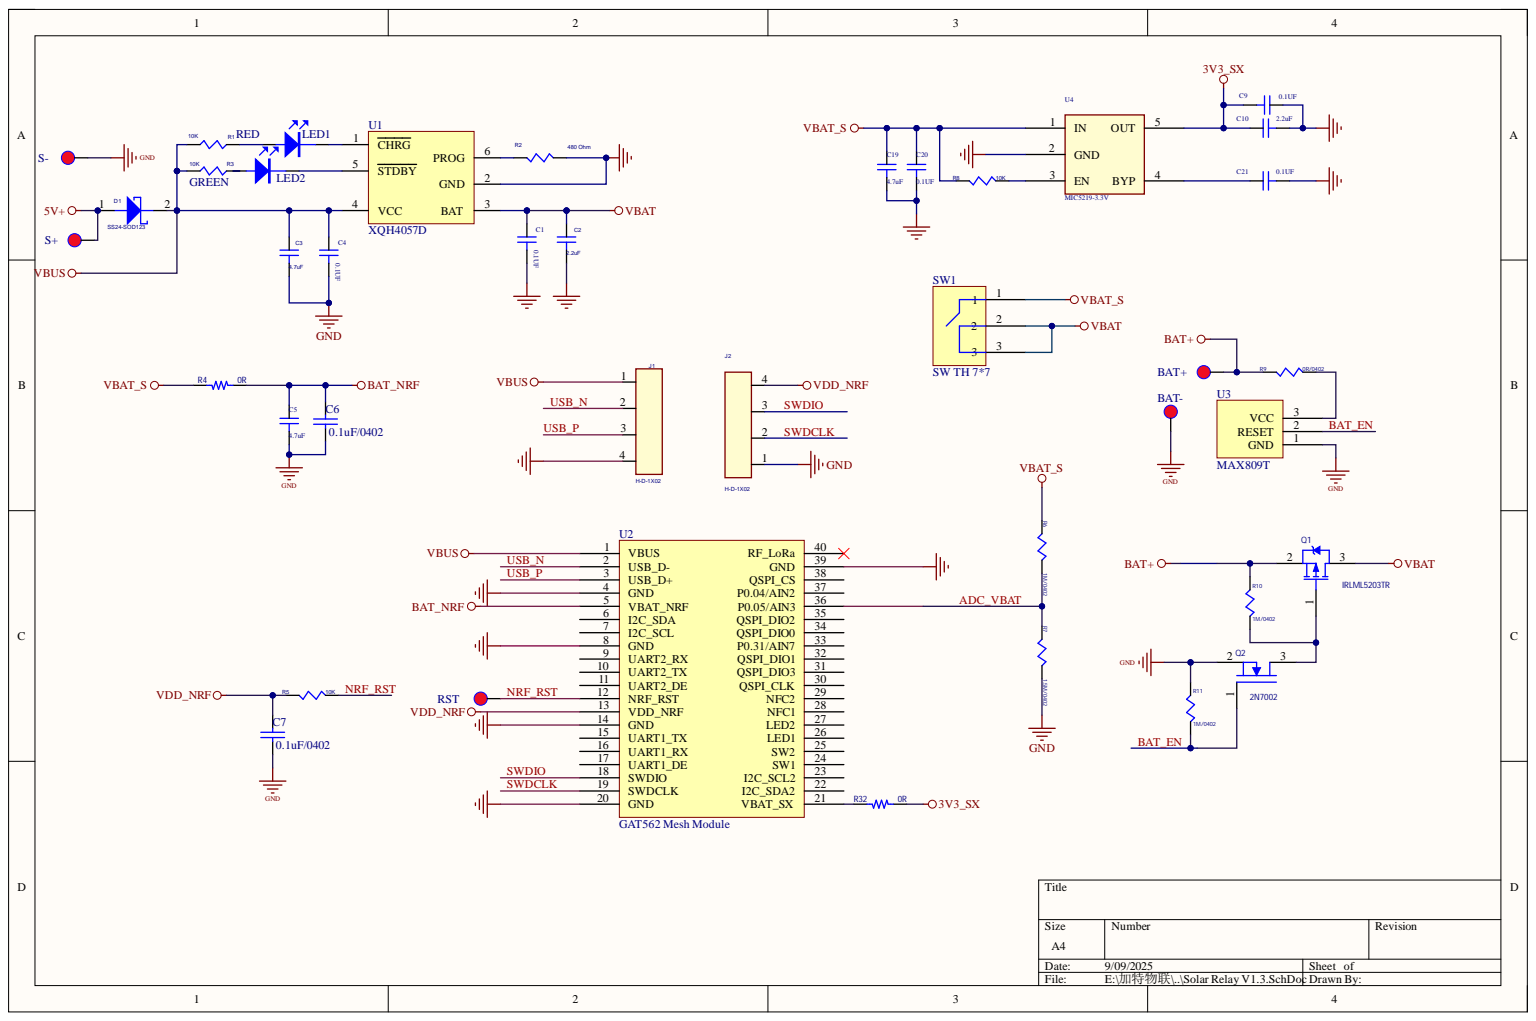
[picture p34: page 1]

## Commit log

2026-01-30 Rename 模组特性拓扑图.png to GAT562 Mesh Module 特性图.png
2026-01-30 Rename IO标注.png to GAT562 Mesh EVB Pro IO标注.png
2026-01-30 Rename GAT562 Mesh EVB PRO介绍.png to GAT562 Mesh EVB PRO特性图.png
2026-01-30 Rename GAT562 Mesh模组封装定义.pdf to GAT562 Mesh Module封装定义.pdf
2026-01-30 Rename GAT562 Mesh Solar Relay V1.3.pdf to GAT562 Mesh Solar Relay V1.3 SCH.pdf
